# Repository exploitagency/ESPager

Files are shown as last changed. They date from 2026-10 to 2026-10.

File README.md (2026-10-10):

```
######################################
ESPager
A GSC and POCSAG Encoder for ESP32 C3
######################################
Written by Hardcore Corey Harding
######################################
Licensed: GPL v3.0
######################################
```
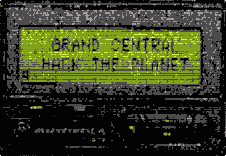
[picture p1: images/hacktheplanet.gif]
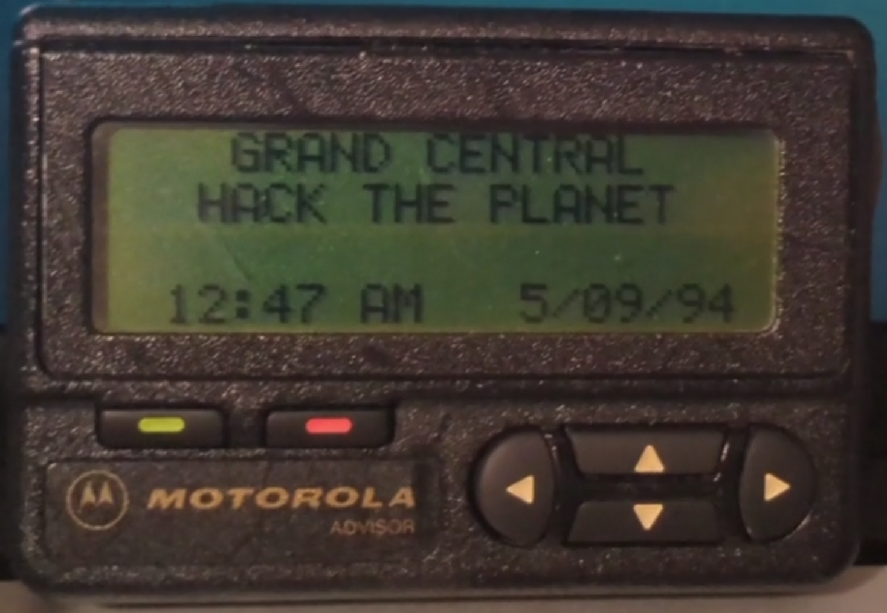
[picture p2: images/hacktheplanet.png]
   
<br>
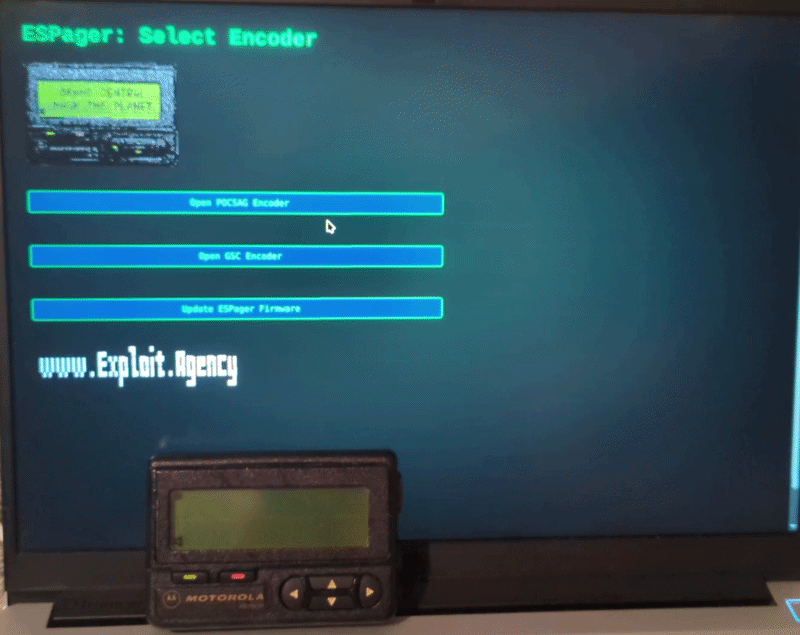
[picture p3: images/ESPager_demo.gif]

<br>

* Note: The pager related instructions are specifically tailored to the 1st Generation Motorola Advisor but ESPager should be able to send pages to similar pagers using the same methods as described in the readme.  

--------------------
# What is it?  

<i>
<table>
  <tr>
    <td><br>Video demonstrating web interface<br>(No PBX Required)</td>
    <td><br>Video demonstrating integration with PBX<br>(FreePBX 17 / Asterisk)</td>
  </tr>
</table>
</i>

* ESPager is capable of sending either GSC or POCSAG encoded pages to a pager through ESPager's retro inspired web interface.  
* The radio module is removed from the pager and replaced with an ESP32 C3.  
* The ESP32 has a GPIO pin connected directly to the pager's data in pin that was formerly occupied by the pager's radio module.  
* ESPager effectively bit bangs the encoded message directly into the pager's data in pin, thus signalling a page on the pager.  
* You can send a page either through ESPager's web interface or by using URL GET Requests with the proper parameters.  Using the GET Request API you can now more easily integrate this project into an Asterisk PBX to send a message to your pager.  

<a href="images/web_root.png">
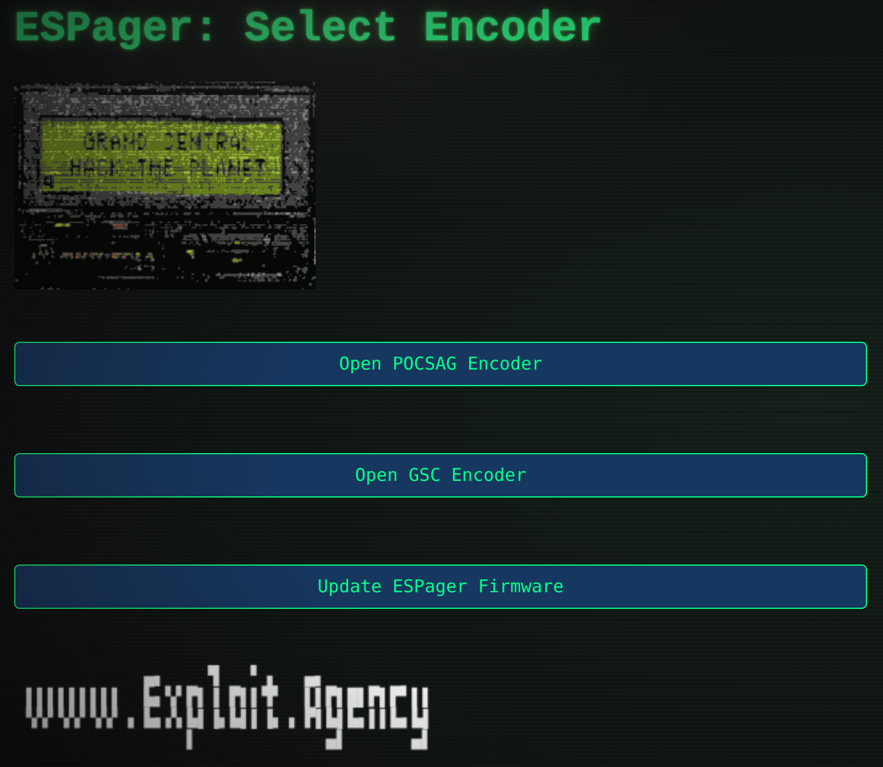
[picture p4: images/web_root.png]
Full-size image
  
</a>

<a href="images/web_pocsag_encoder.png">
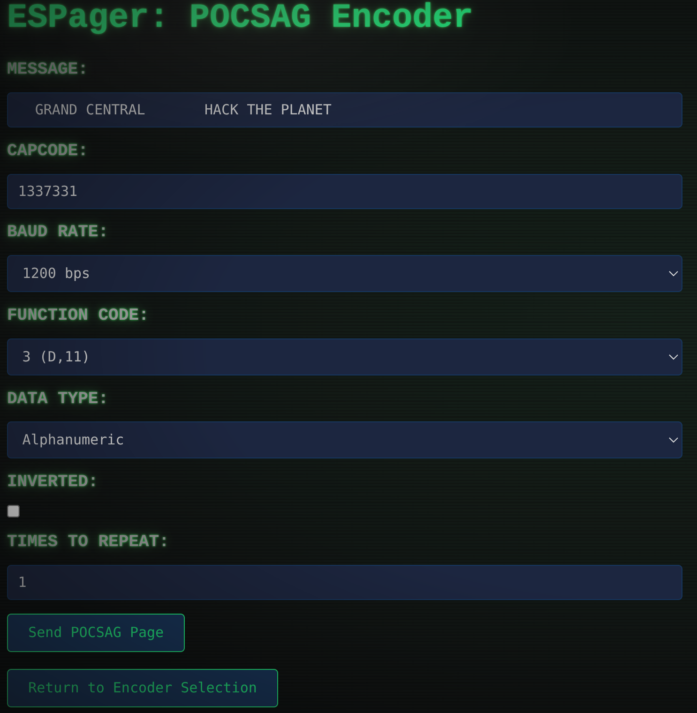
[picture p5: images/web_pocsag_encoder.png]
Full-size image
  
</a>

<a href="images/web_pocsag_encoded.png">
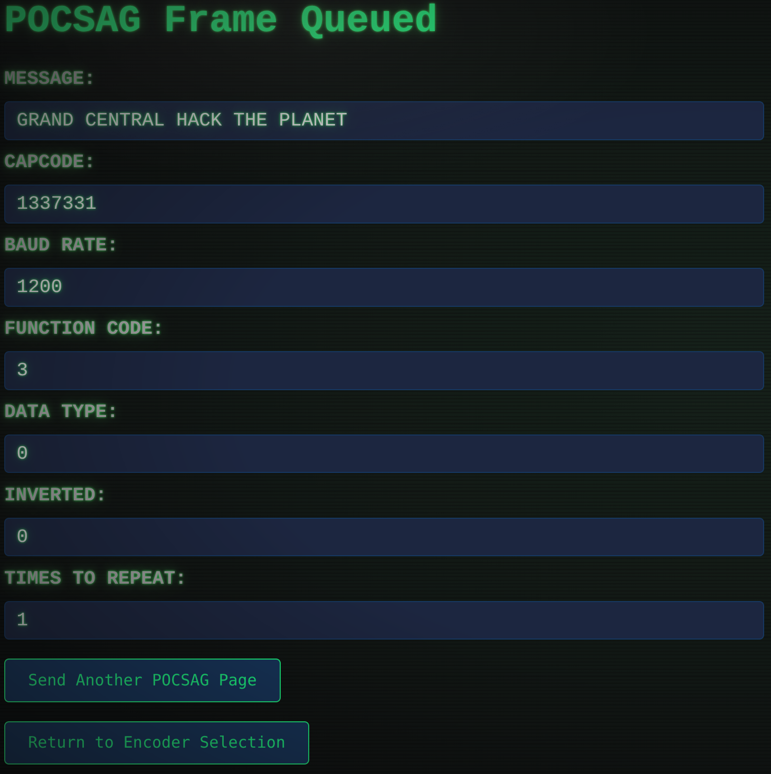
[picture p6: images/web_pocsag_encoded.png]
Full-size image
  
</a>

<a href="images/web_gsc_encoder.png">
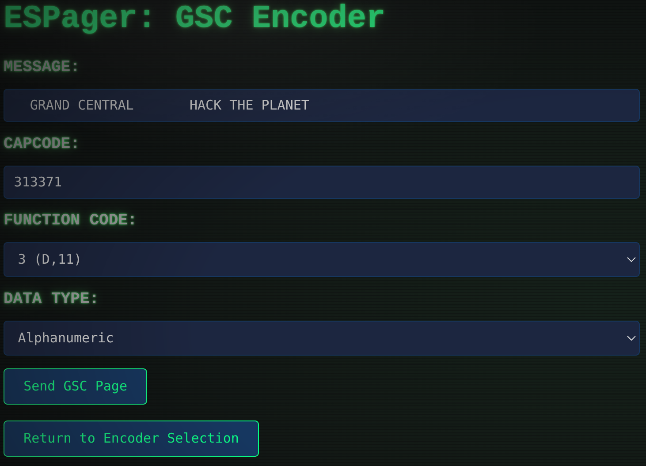
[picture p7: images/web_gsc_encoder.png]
Full-size image
  
</a>

<a href="images/web_gsc_encoded.png">
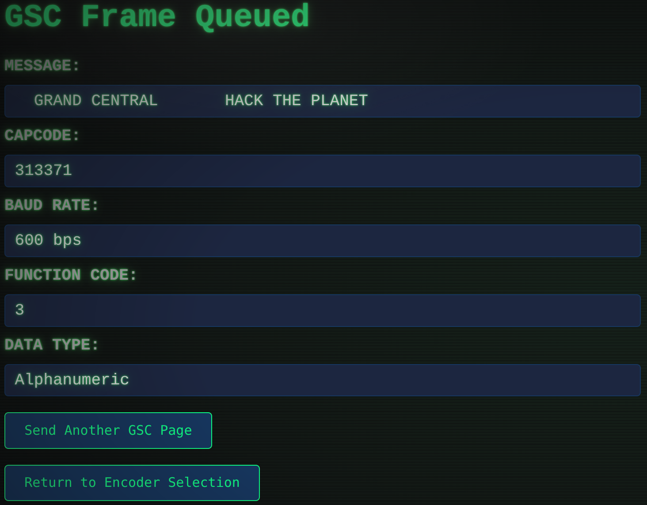
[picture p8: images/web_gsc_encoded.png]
Full-size image
  
</a>

--------------------
# BOM  

** Note: Most of these items can only be found on AliExpress or through similar vendors  
* 1st Generation Motorola Advisor (or Pager that supports POCSAG or GSC)  
* XIAO ESP32 C3 with built in battery charging (or Generic ESP32-C3 SuperMini)  
* 10440 Button-Top 3.7v Vapcell F4 450mAh (or Generic USB C Rechargeable 3.7v 10440 750mWh 200mAh, maybe a 601230?)  
* Tiny Out 1A LDO 1.8V (or mini DC-DC Buck Converter 1.5v output voltage with 2.5v-6.0v input voltage)  
* 3.7v 1S 2.5A li-ion BMS Protection Module with Overdischarge protection (Round type that goes on end of 18650 is smallest I found)  
* Assorted Color Wire (I used solid core 22awg)  
* Wiring harness tape(Tesa cloth fabric tape)  

Optional:  
* Serial UART adapter for programming pager (Worked best in DOSBOX: RadioMaster ExpressLRS USB UART Flasher V2)  
* 3d printed TPU programming POGO adapter for Motorola Advisor (Included in 3d_prints folder)  
* Male to Female DuPont jumper wires for 3d prints  

--------------------
# Instructions  

An ESP32 C3 running the code contained within this repo is installed inside a Motorola Advisor pager with slight hardware modifications.  

--------------------
### Programming the Motorola Advisor  
--------------------
* 3d print (TPU) and assemble the POGO adapter for the Motorola Advisor
* Remember to connect UARTs TX to Pagers RX and UARTs RX to Pagers TX
* Programming software is available at this repo (https://github.com/goshante/motorola-advisor-linguist) and various locations online.  
* For ESPager's default settings to work out of the box be sure to set all pager settings to exactly mirror the images below.  
<a href="images/motorola_advisor_programming_pins.jpg">
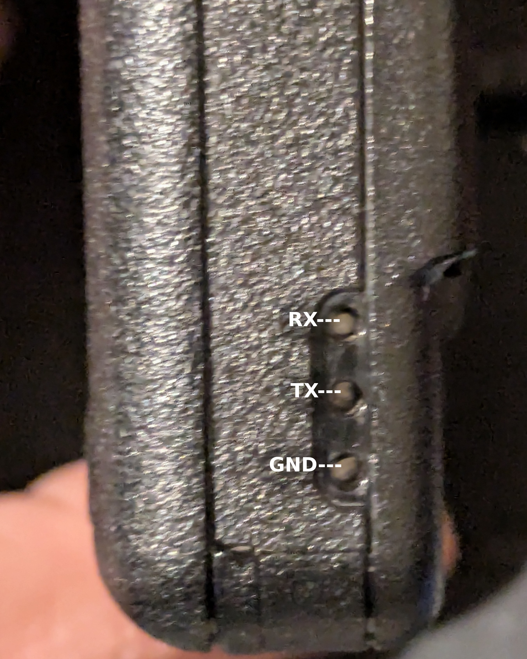
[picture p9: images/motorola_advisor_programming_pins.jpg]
Full-size image
  
</a>

<a href="images/advisor_prog_jig1.jpg">
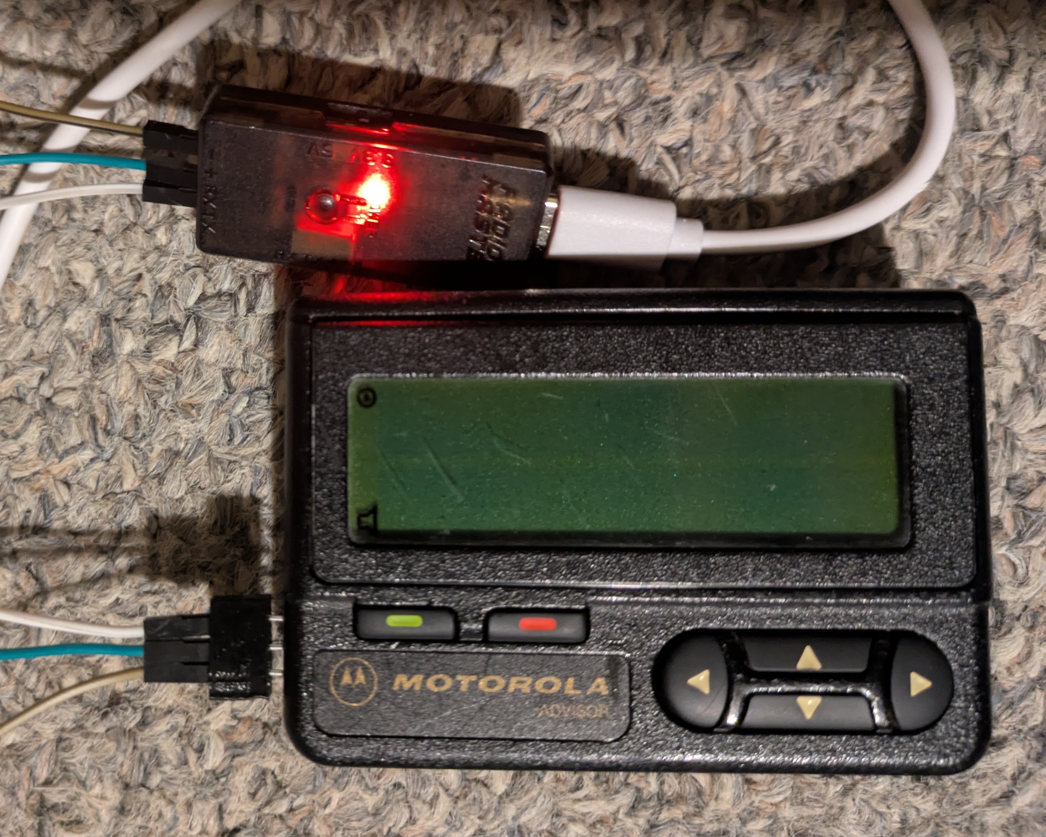
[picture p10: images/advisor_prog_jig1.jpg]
Full-size image
  
</a>

<a href="images/advisor_prog_jig2.jpg">
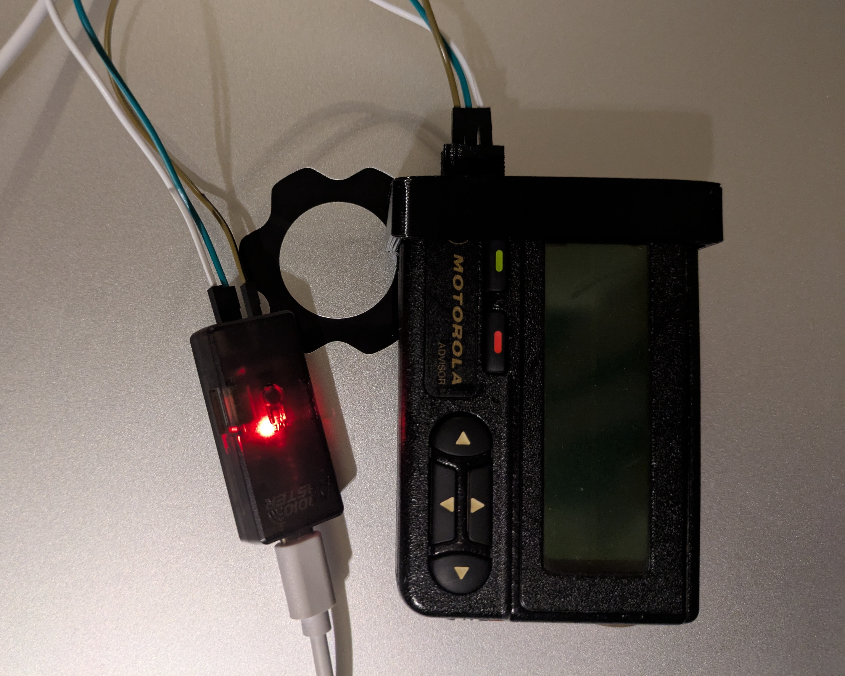
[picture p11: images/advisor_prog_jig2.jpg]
Full-size image
  
</a>

<br>

<a href="images/pocsag1.png">
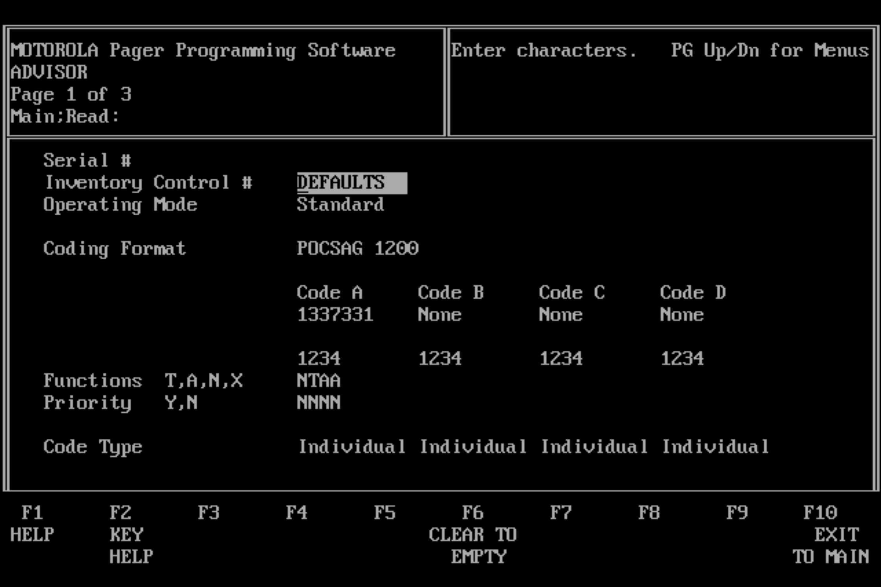
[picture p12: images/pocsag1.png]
Full-size image
  
</a>

<a href="images/pocsag2.png">
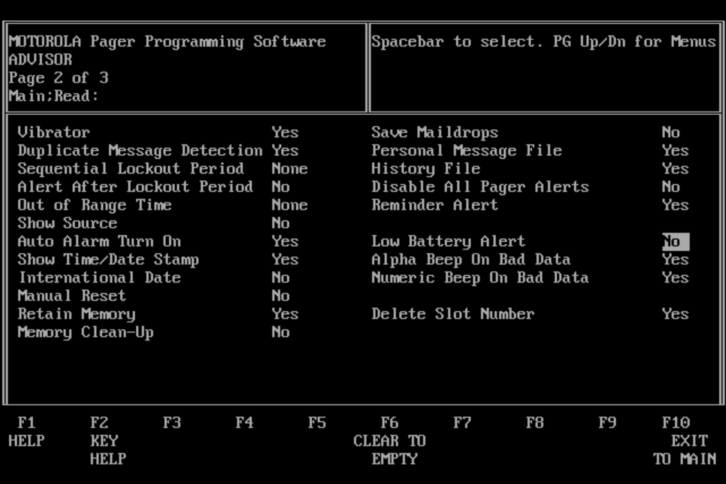
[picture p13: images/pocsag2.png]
Full-size image
  
</a>

<a href="images/pocsag3.png">
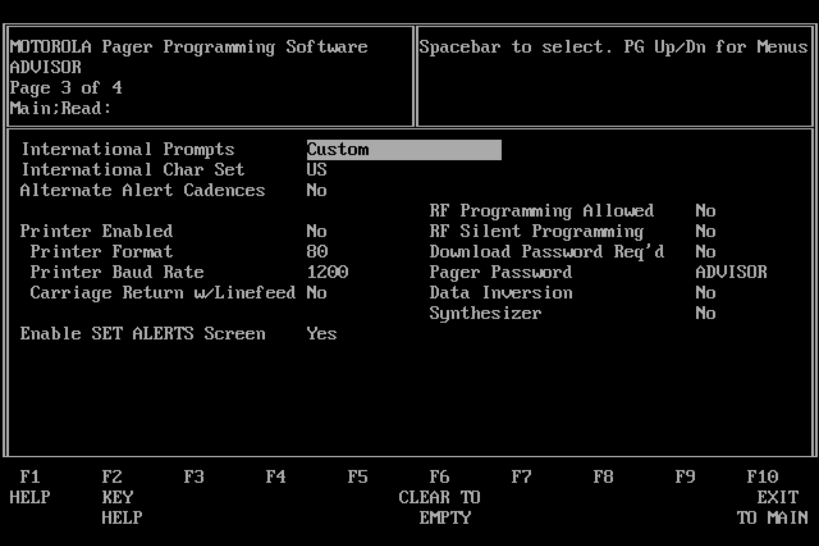
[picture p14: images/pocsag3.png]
Full-size image
  
</a>

<a href="images/pocsag4.png">
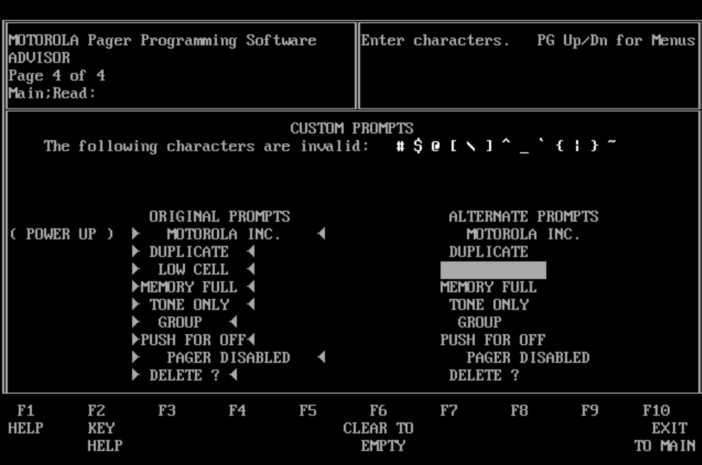
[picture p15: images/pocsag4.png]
Full-size image
  
</a>

<br>

<a href="images/gsc1.png">
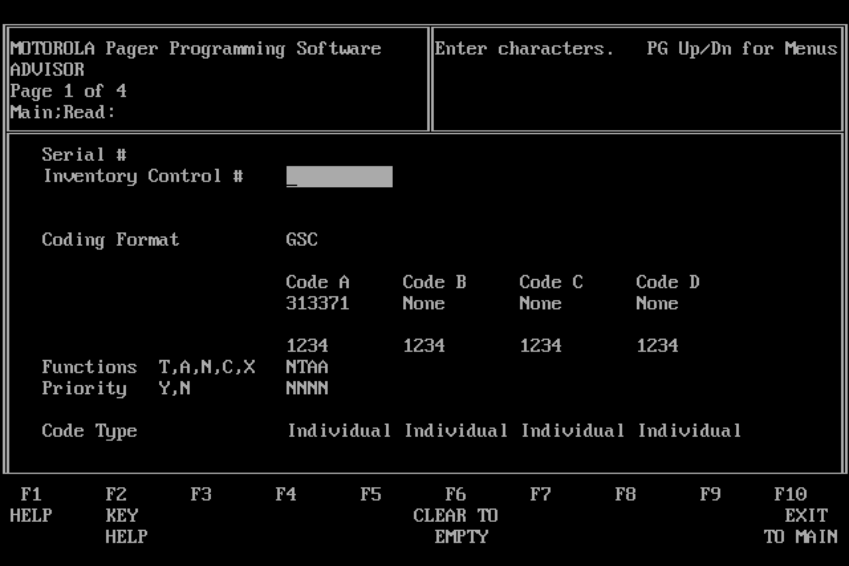
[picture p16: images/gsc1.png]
Full-size image
  
</a>

<a href="images/gsc2.png">
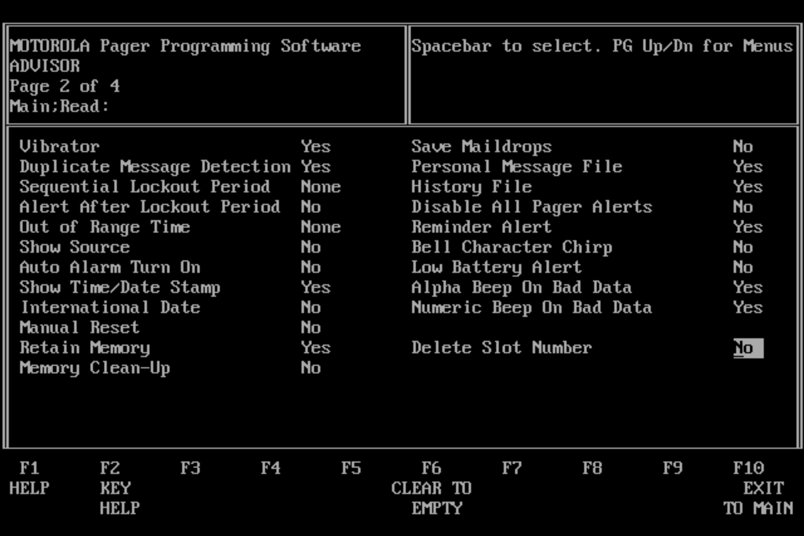
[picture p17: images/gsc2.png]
Full-size image
  
</a>

<a href="images/gsc3.png">
  Full-size image
</a>

<a href="images/gsc4.png">
  Full-size image
</a>

--------------------
### Opening the Motorola Advisor  
--------------------
* Refer to photos below instructions as you follow along.
* Slide battery tray lock away from the compartment to unlock it.  Slide battery tray cover away from the pager to open it. Remove the battery if present.
* Locate the lanyard loop pin on bottom side of the pager.  Very lightly lift the locking tab closest to the lanyard loop pin.  Slide the locking tab from the bottom and up towards the lanyard loop and it should pop out.  
* Gently pry the bottom corner near the positive battery terminal using the battery tray as leverage and the body should pop open on that side.  Gently roll the body towards the still locked side to open it.  
* Locate the radio board and gently wiggle and lift up and away from the main pcb to free it from the header pins.  
<a href="images/motorola_advisor_open_1.jpg">
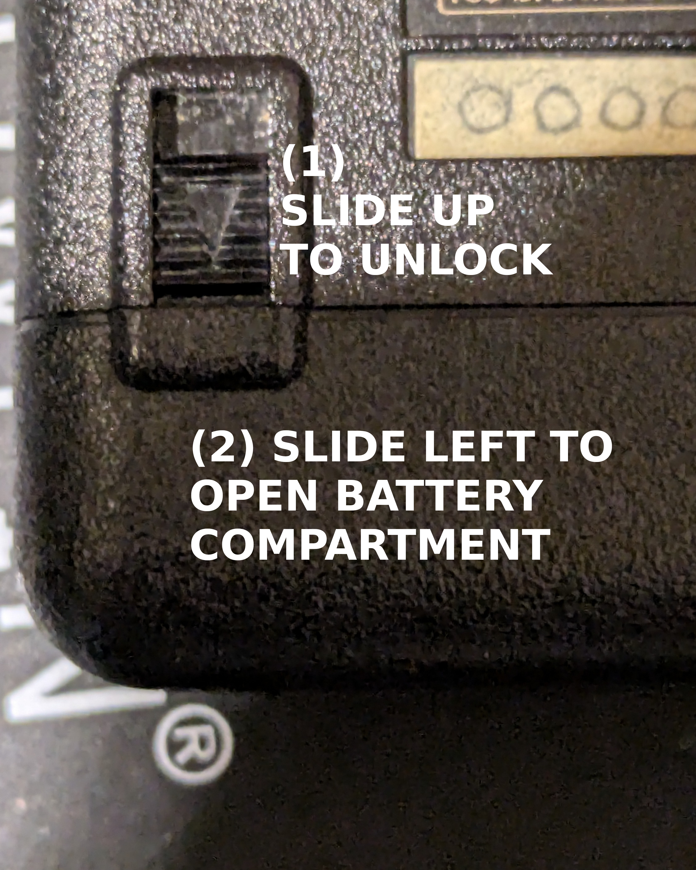
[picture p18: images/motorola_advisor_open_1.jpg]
Full-size image
  
</a>

<a href="images/motorola_advisor_open_2.jpg">
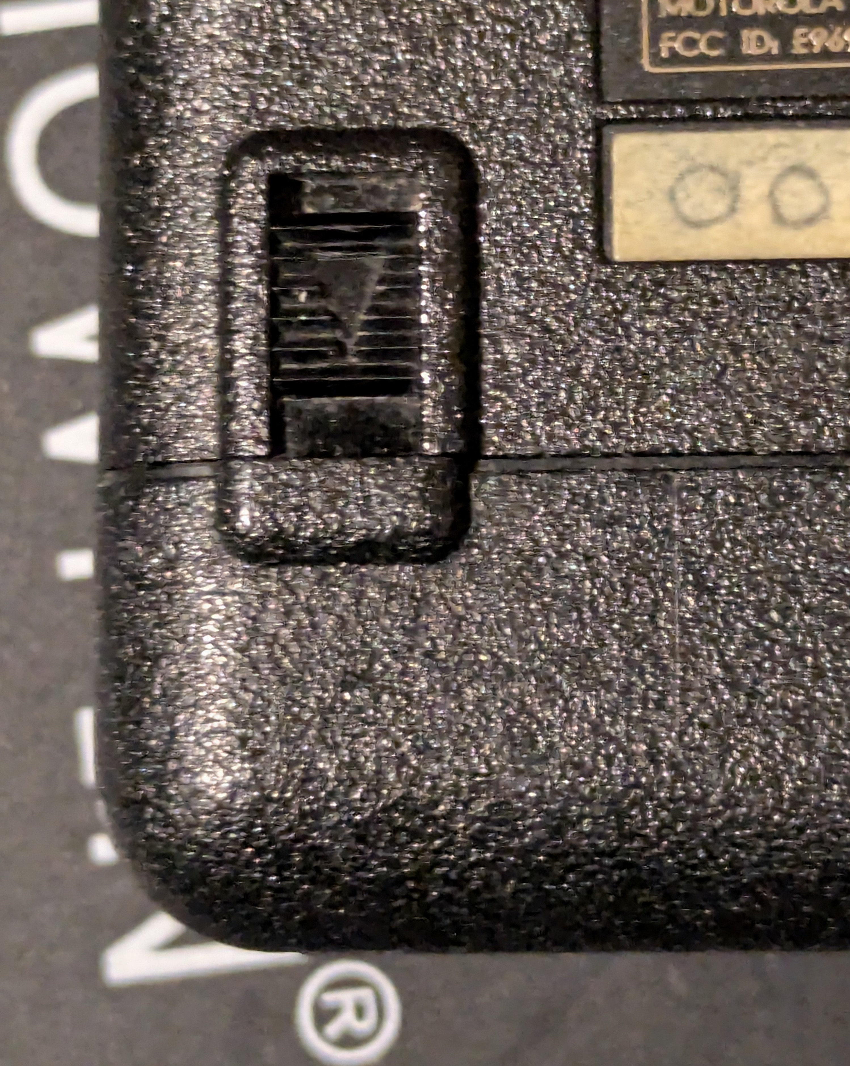
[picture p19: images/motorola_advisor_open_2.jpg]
Full-size image
  
</a>

<br>

<a href="images/motorola_advisor_open_3.jpg">
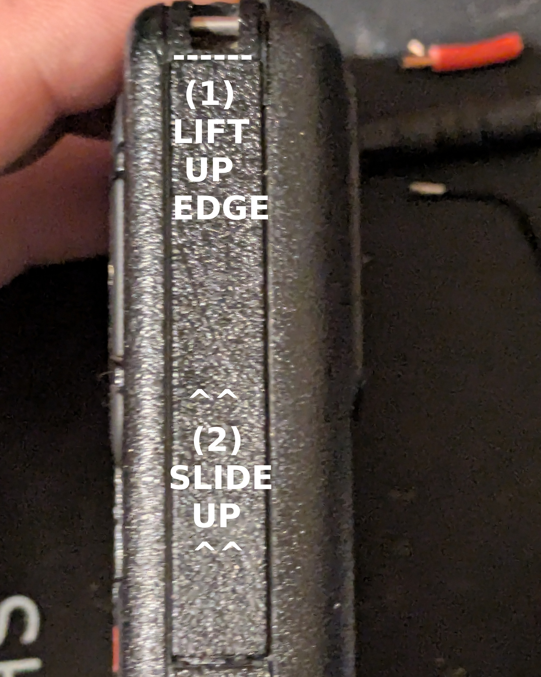
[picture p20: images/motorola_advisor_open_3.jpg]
Full-size image
  
</a>

<a href="images/motorola_advisor_open_4.jpg">
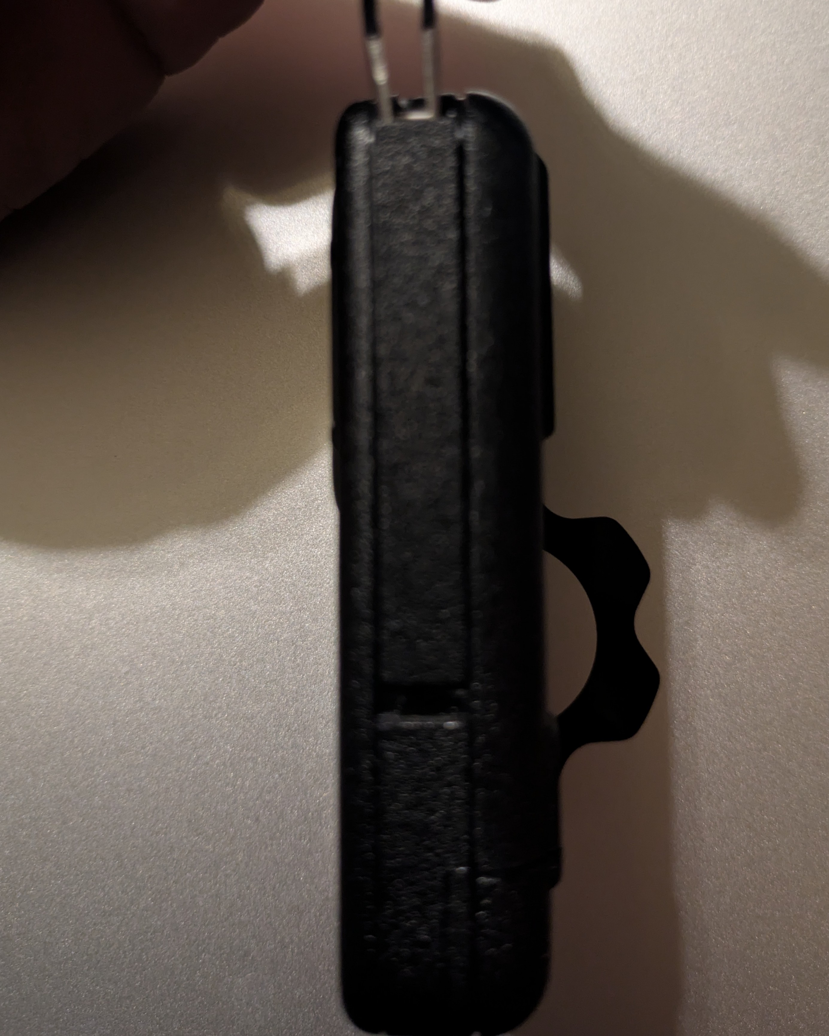
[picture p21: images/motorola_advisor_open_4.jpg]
Full-size image
  
</a>

<a href="images/motorola_advisor_open_5.jpg">
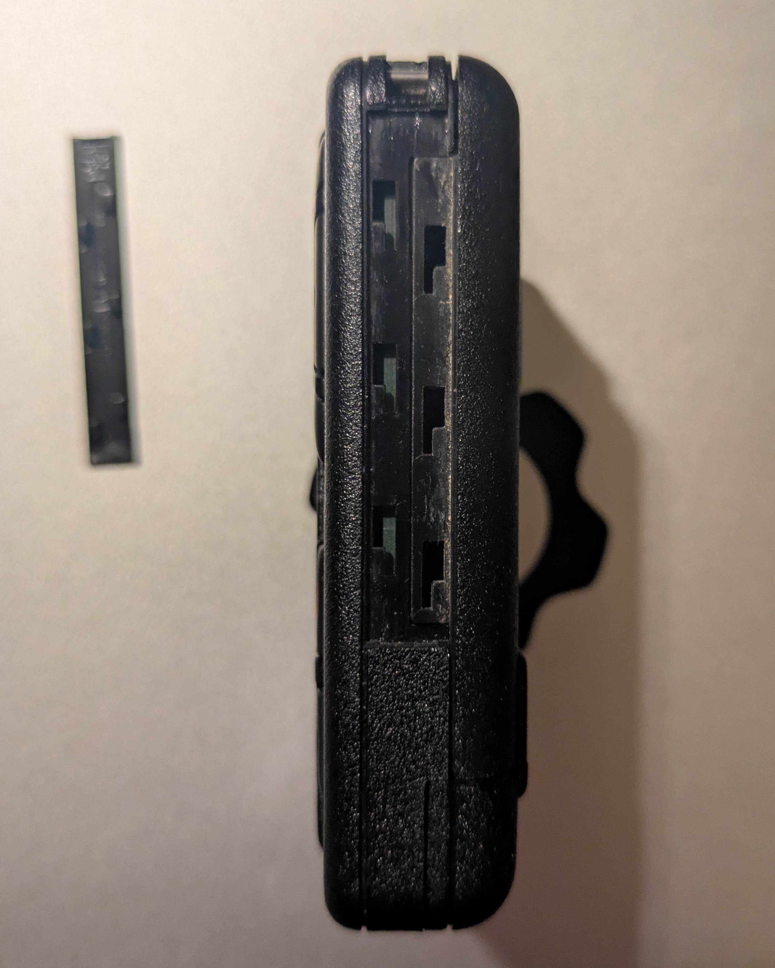
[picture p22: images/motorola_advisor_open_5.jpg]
Full-size image
  
</a>

<br>

<a href="images/motorola_advisor_open_6.jpg">
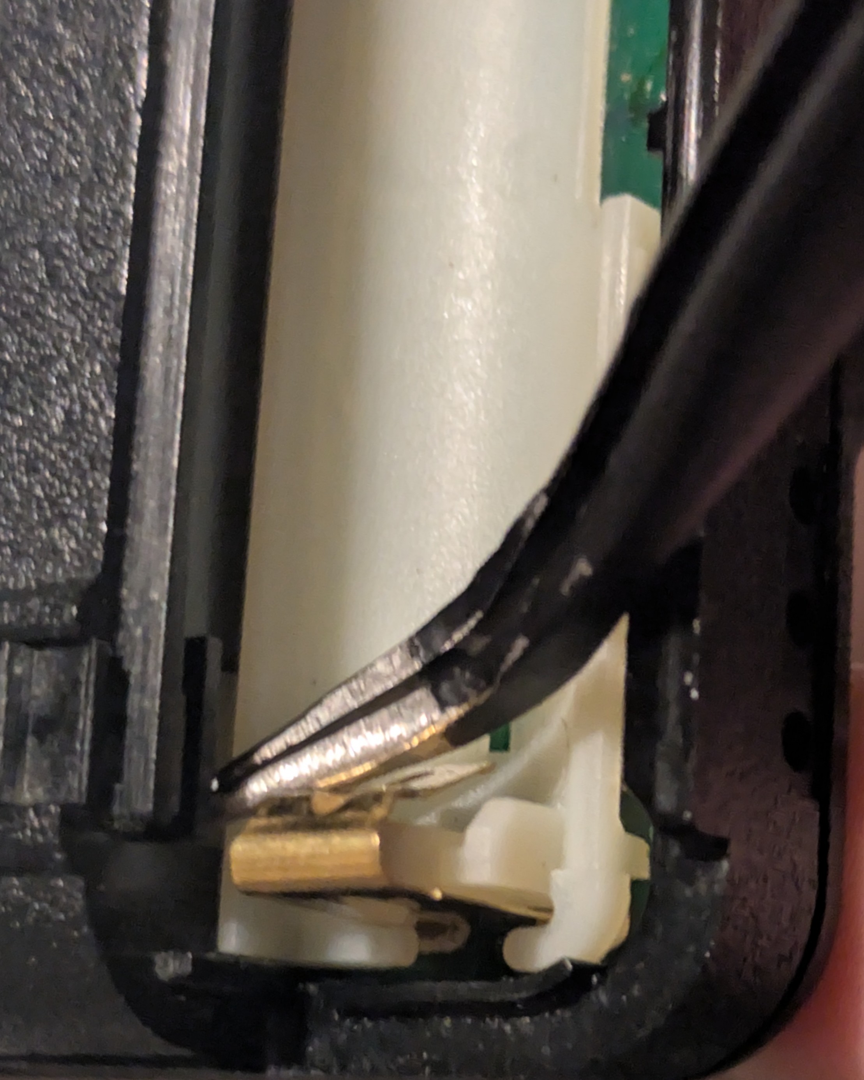
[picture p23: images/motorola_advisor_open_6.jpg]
Full-size image
  
</a>

<a href="images/motorola_advisor_open_7.jpg">
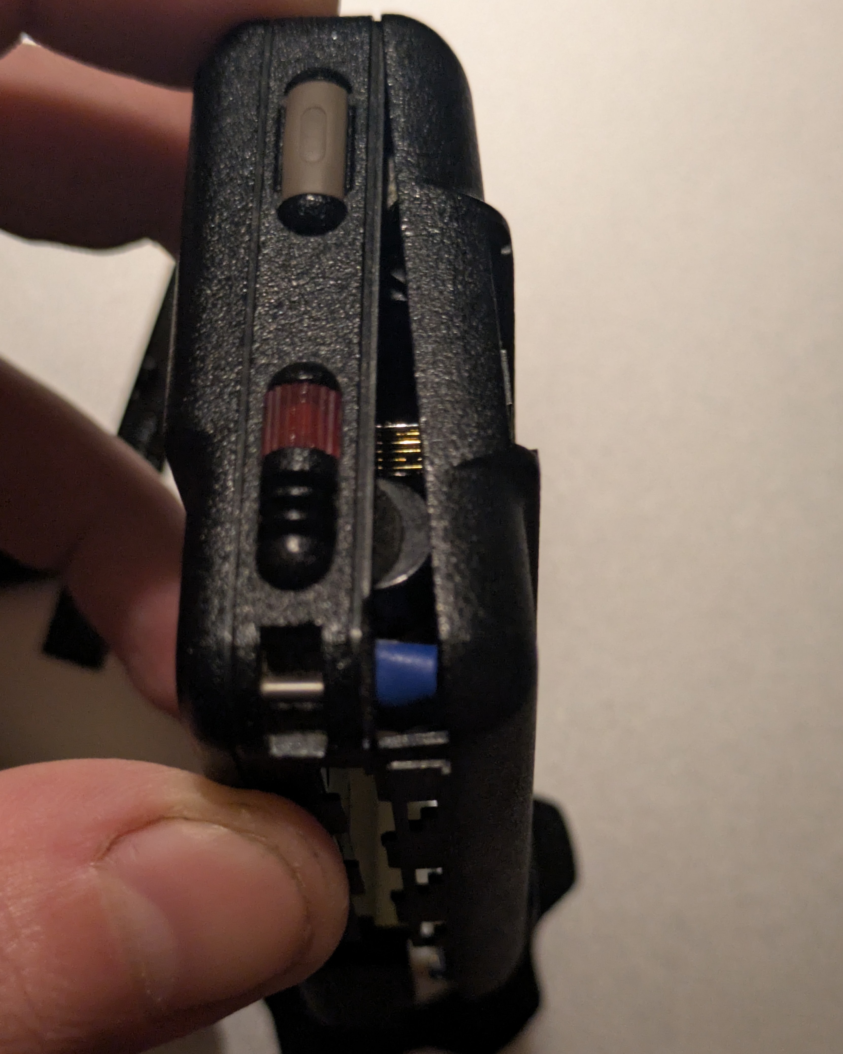
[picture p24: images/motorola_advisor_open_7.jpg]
Full-size image
  
</a>

<a href="images/motorola_advisor_open_8.jpg">
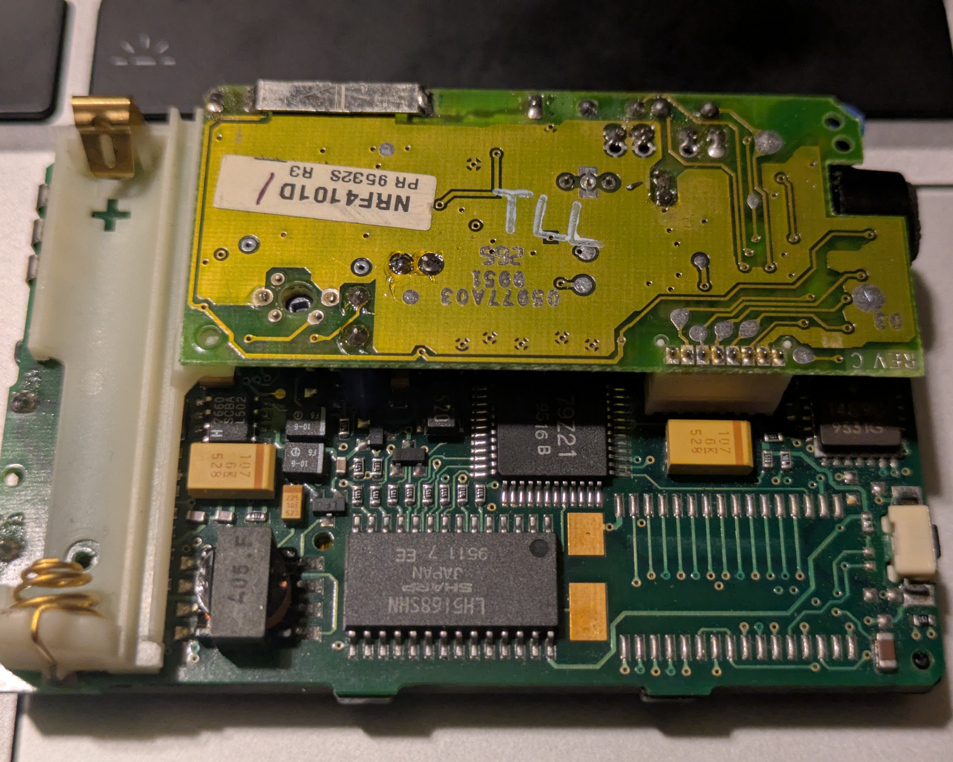
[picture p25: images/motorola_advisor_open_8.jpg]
Full-size image
  
</a>

--------------------
### Modifying the Motorola Advisor and Installing ESP32 C3  
--------------------

** WARNING: Do not connect USB when battery power is also connected unless your board has specific hardware to support it!  
* Desolder the battery holder.  On the positive side clip the legs off the bottom that protrude through the pcb.  On the negative side, bend the leg towards the inside of the pager.  Solder you main battery wires to the battery holder.  Clip the corner of the pager's rear cover as pictured to make room for the battery wire to pass through.  Clip the nub off the bottom of the battery holder under the positive side to make room for the wiring underneat it.  
* Solder the 3.7v wires from the battery holder to the BMS input as seen in wiring diagram.  
* Solder the 3.7v wires from the BMS output directly to the ESP32-C3's 5v input and GND and to the 1.5v buck converters input as seen in wiring diagram.(ESP32-C3 5v input can be powered by 3.5v-6v and a fully charged 10440 is 4.2v)  
* Solder the 1.5v wires onto the pager's main pcb as pictured and solder those wires to the output of the buck converter as seen in wiring diagram.  Cover the wires on the pager's main pcb to prevent feeding the pager 3.7v if the battery trays positive somehow made contact.  
* Solder GPIO 3(Sleep) on the ESP32 C3 to header pin 7(pulse when pager is on) on the pager, solder GPIO 7(Data out) on ESP32-C3 to header pin 4(Data In) of pager.  
* Verify that the ESP32 and pager share a common ground plane by checking continuity between both grounds.  If not connect the ground from ESP32 to a ground on the pager, but I have a common ground plane through my power supply configuration.  
* Tape off the inside of the pager to prevent shorts, tape of the bms, buck converter, and ESP32-C3.  
* Assembly is reverse of disassembly.  

<a href="images/ESPager_wiring_XIAO_tinyout1a.png">
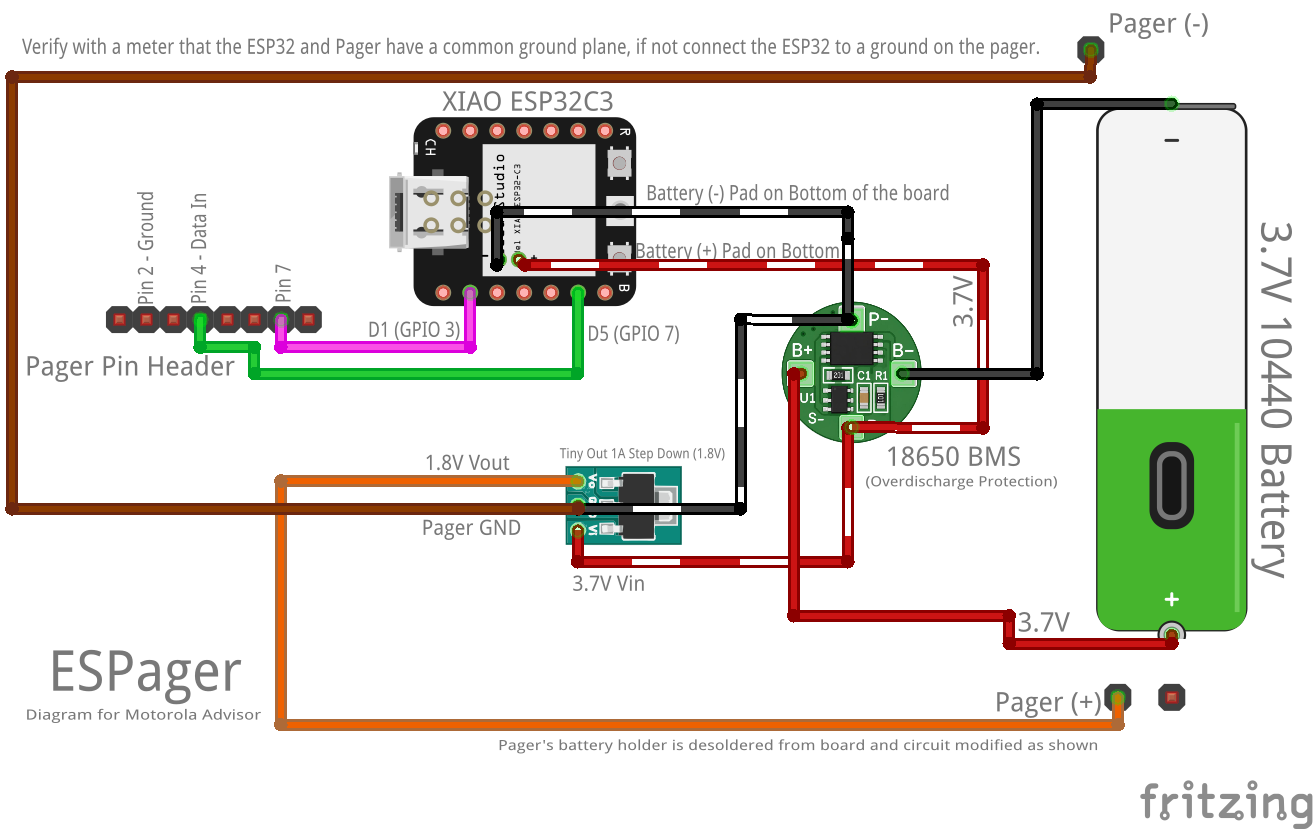
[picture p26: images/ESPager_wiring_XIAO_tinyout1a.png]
Full-size image
  
</a>

<a href="images/ESPager_wiring_XIAO.png">
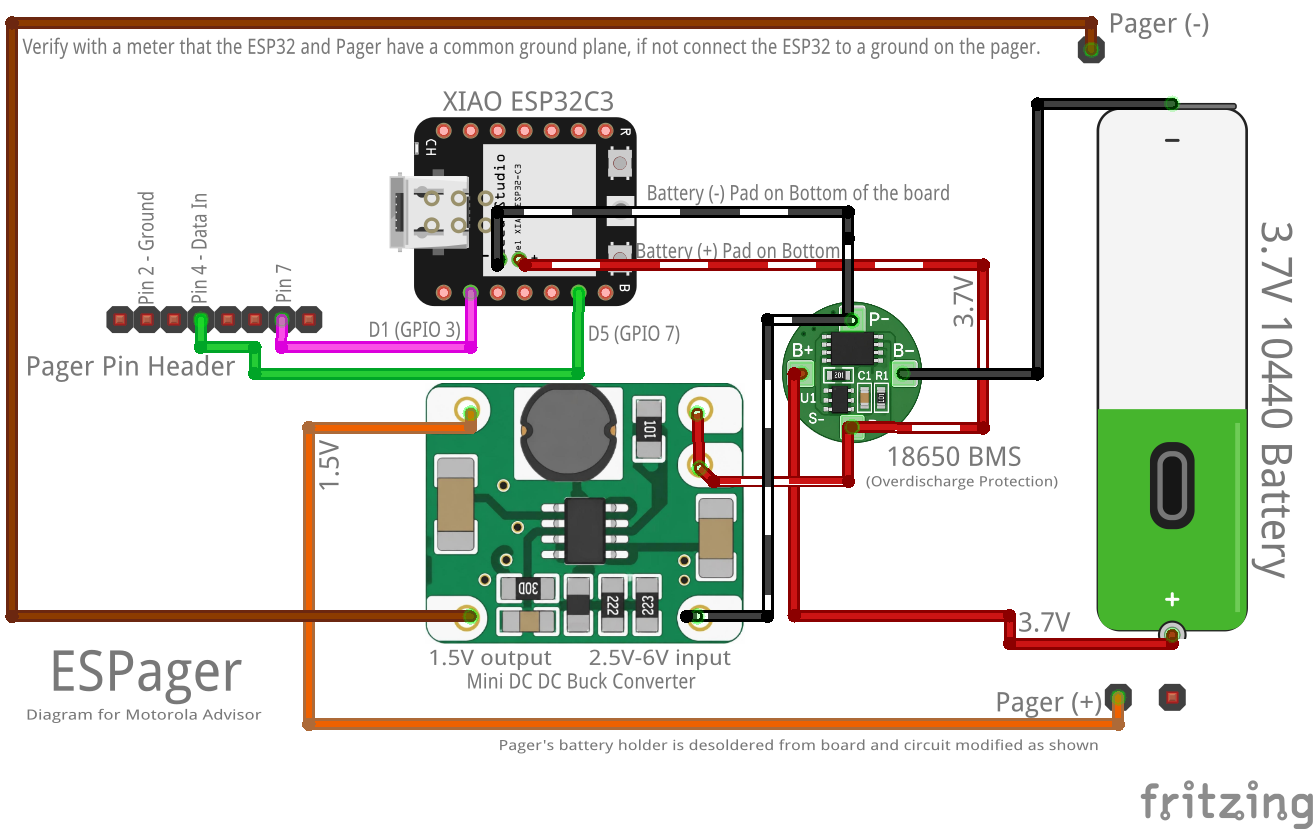
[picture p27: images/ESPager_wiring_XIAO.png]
Full-size image
  
</a>

<a href="images/ESPager_wiring.png">
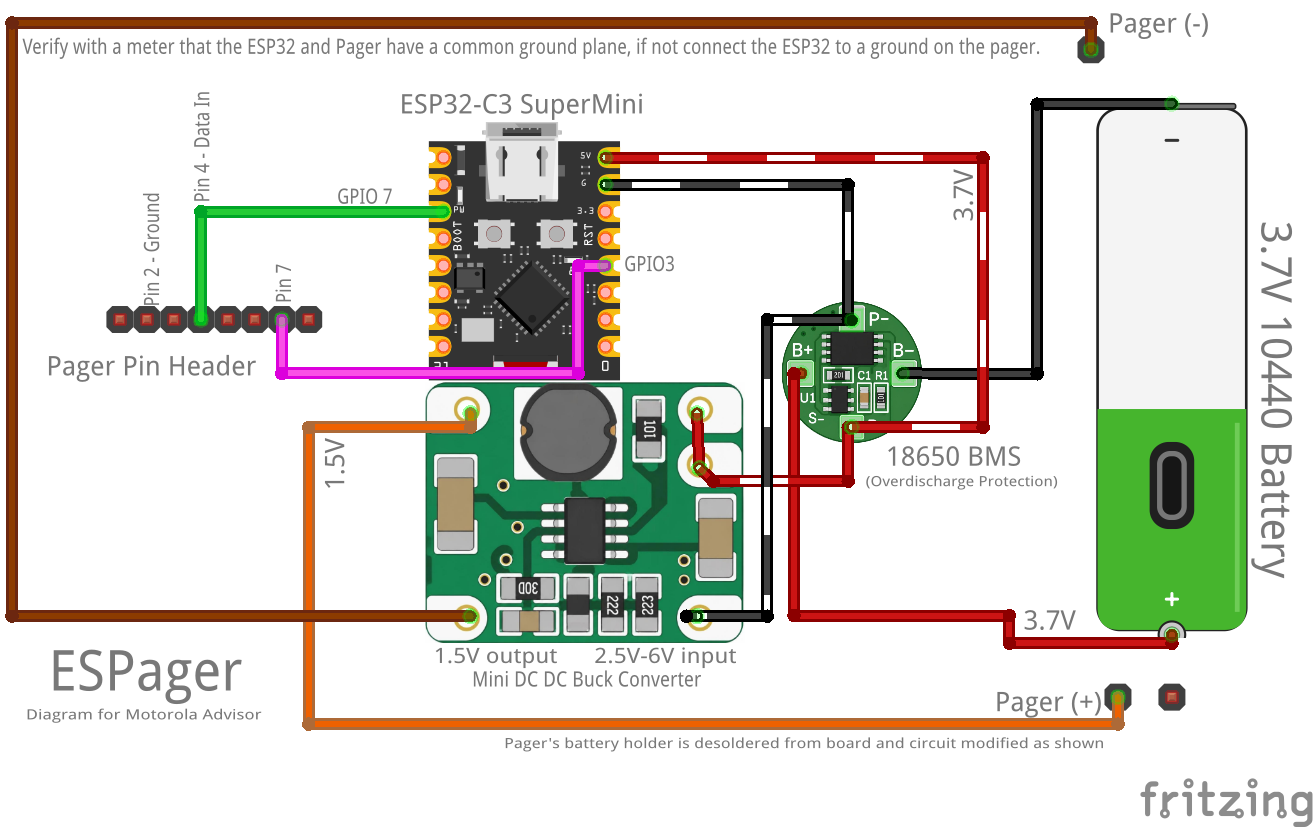
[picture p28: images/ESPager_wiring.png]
Full-size image
  
</a>

<br>

<a href="images/motorola_advisor_radio_header.jpg">
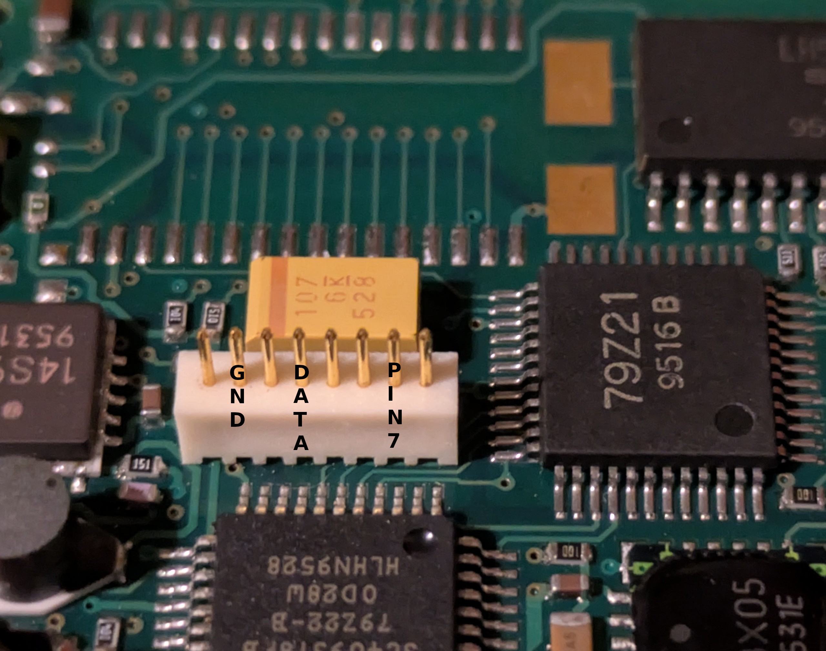
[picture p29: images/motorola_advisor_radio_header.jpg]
Full-size image
  
</a>

<br>

<a href="images/motorola_advisor_battery_tray_negative.jpg">
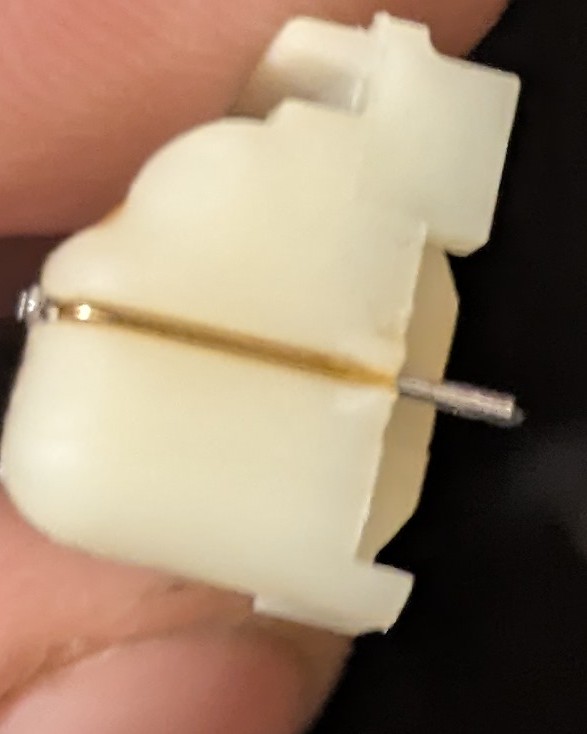
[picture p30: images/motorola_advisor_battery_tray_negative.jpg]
Full-size image
  
</a>

<a href="images/motorola_advisor_battery_tray_positive.jpg">
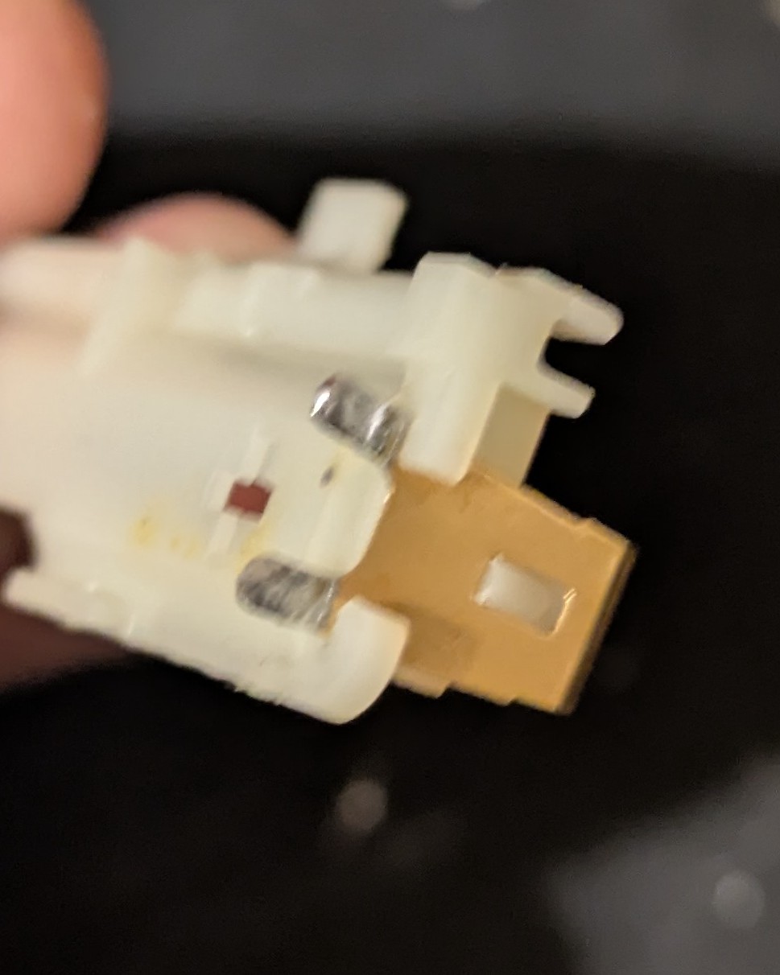
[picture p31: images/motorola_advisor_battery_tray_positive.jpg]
Full-size image
  
</a>

<a href="images/motorola_advisor_battery_tray_negative_mod.jpg">
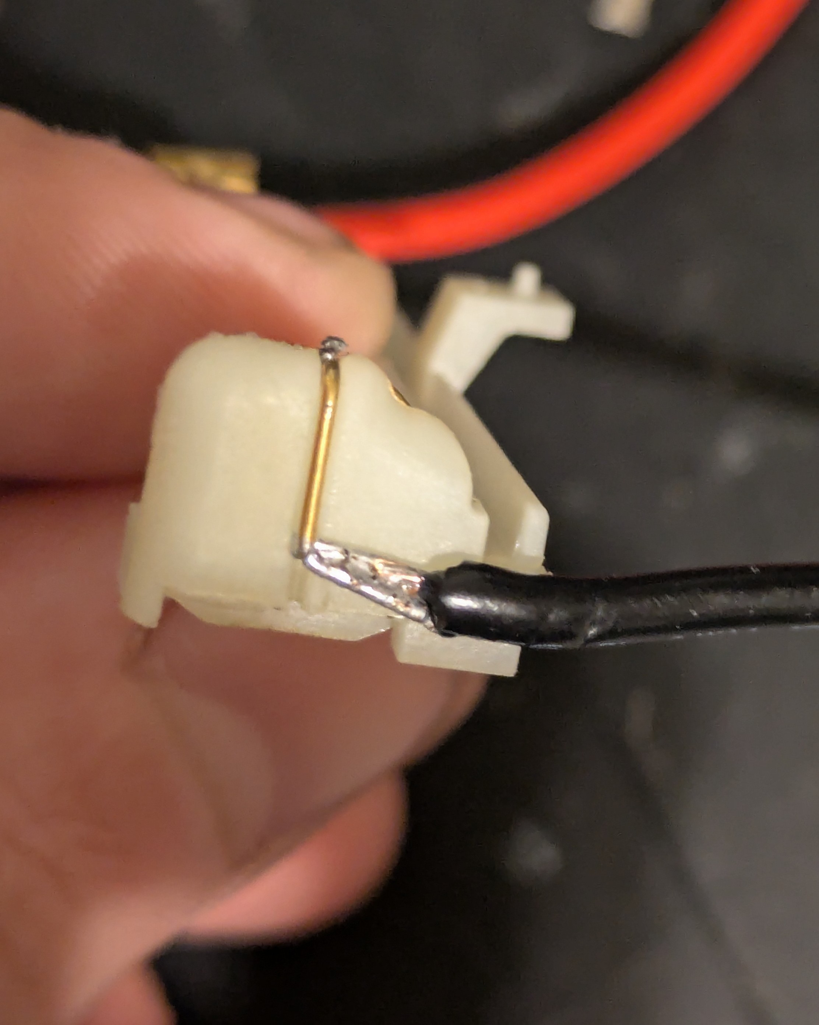
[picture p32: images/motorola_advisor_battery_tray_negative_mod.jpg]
Full-size image
  
</a>

<a href="images/motorola_advisor_battery_tray_positive_mod.jpg">
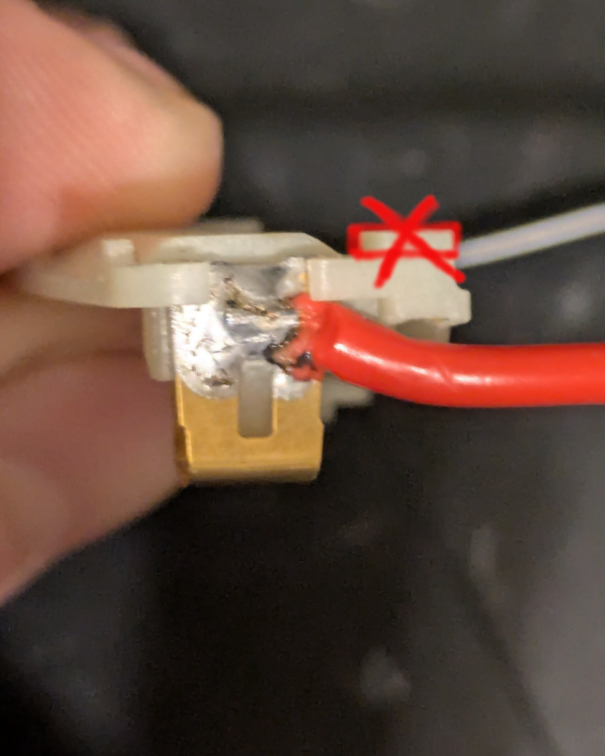
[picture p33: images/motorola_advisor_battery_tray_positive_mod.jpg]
Full-size image
  
</a>

<br>

<a href="images/motorola_advisor_battery_tray_removed.jpg">
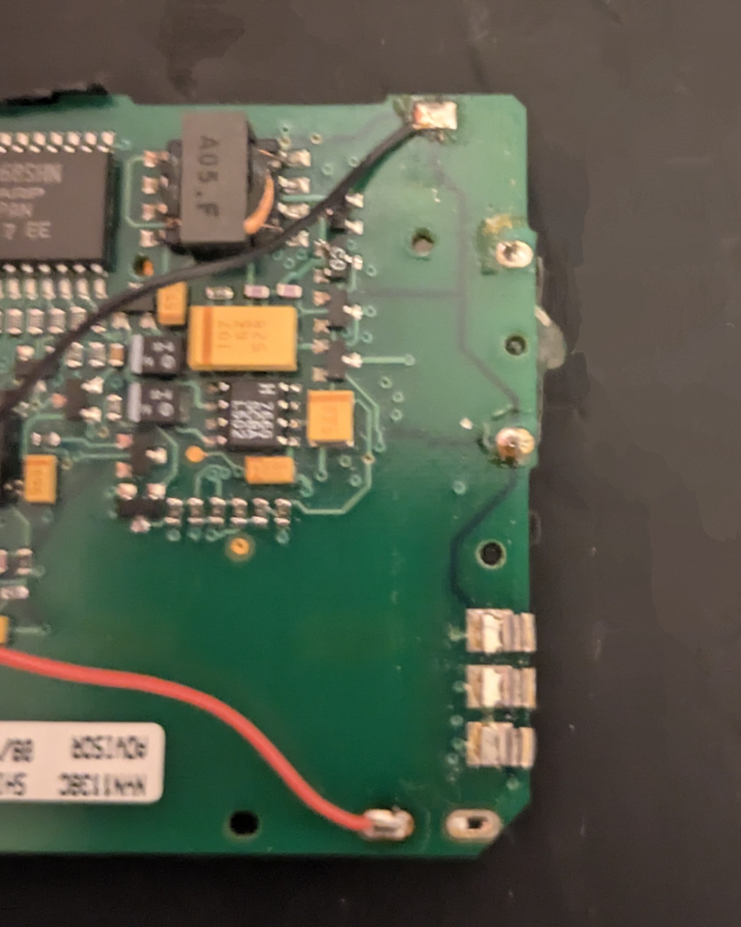
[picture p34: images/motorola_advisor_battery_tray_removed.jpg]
Full-size image
  
</a>

<a href="images/motorola_advisor_battery_tray_trim.jpg">
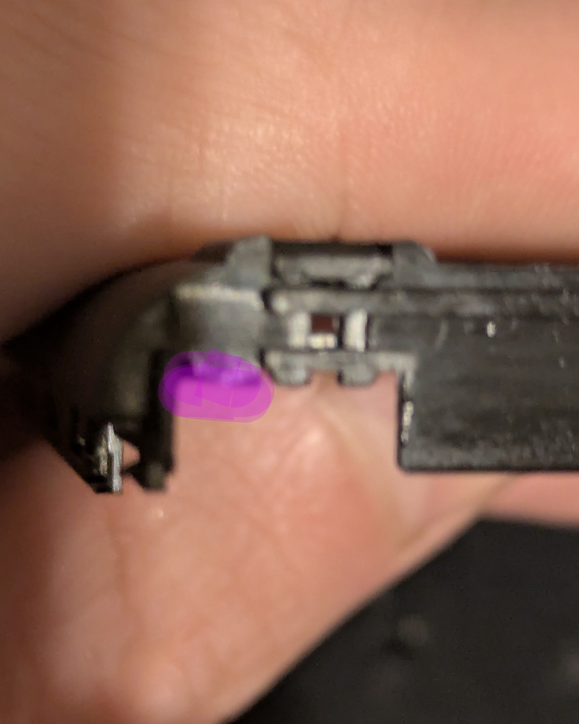
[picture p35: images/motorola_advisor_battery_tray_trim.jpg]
Full-size image
  
</a>

<a href="images/motorola_advisor_battery_tray_closeup.jpg">
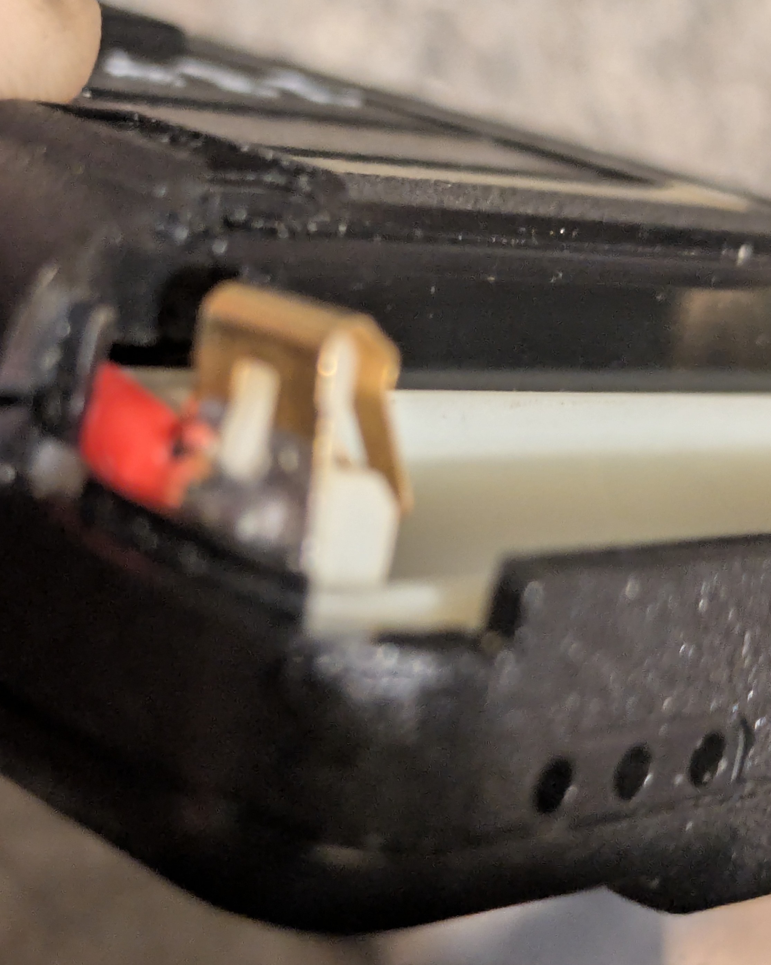
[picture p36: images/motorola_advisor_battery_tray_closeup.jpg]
Full-size image
  
</a>

<a href="images/motorola_advisor_battery_tray_complete.jpg">
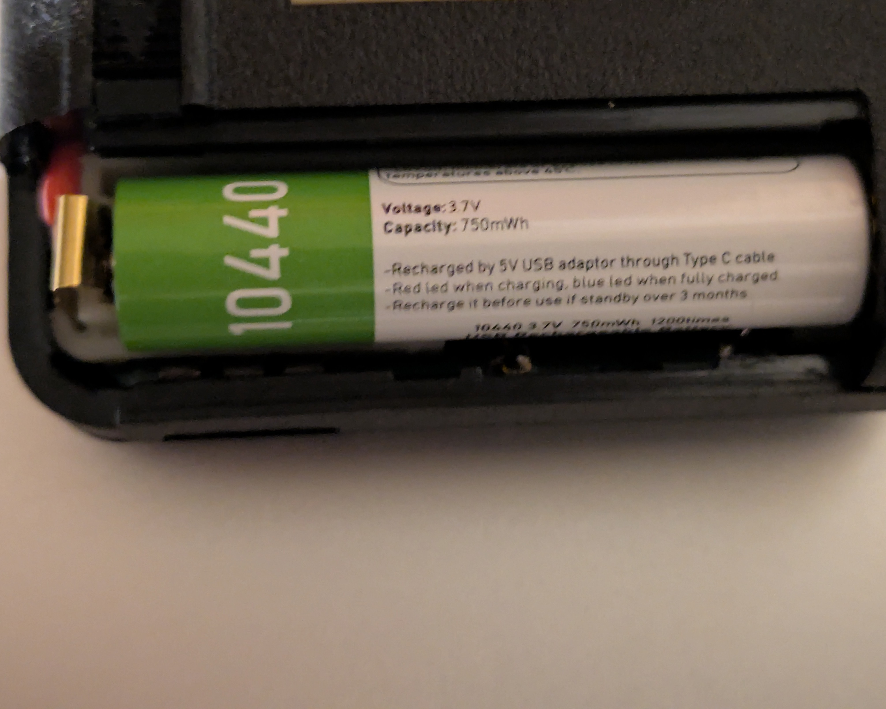
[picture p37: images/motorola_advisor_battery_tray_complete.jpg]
Full-size image
  
</a>

<br>

<a href="images/ESPAGER_XIAO_1.jpg">
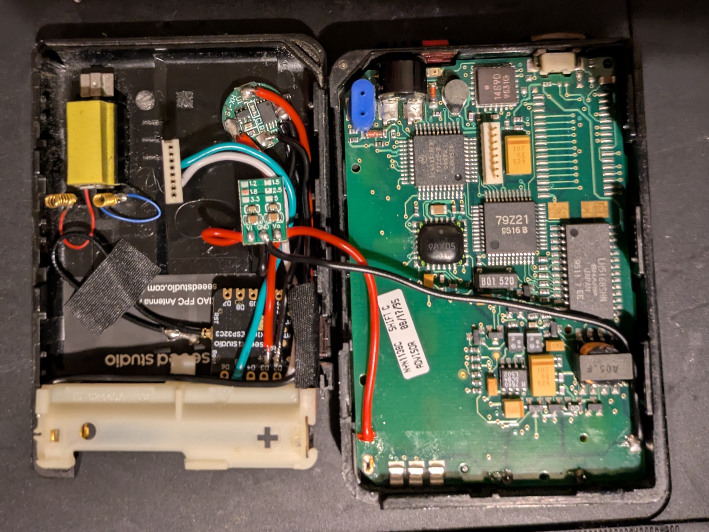
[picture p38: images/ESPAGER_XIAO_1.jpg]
Full-size image
  
</a>

<a href="images/ESPAGER_XIAO_2.jpg">
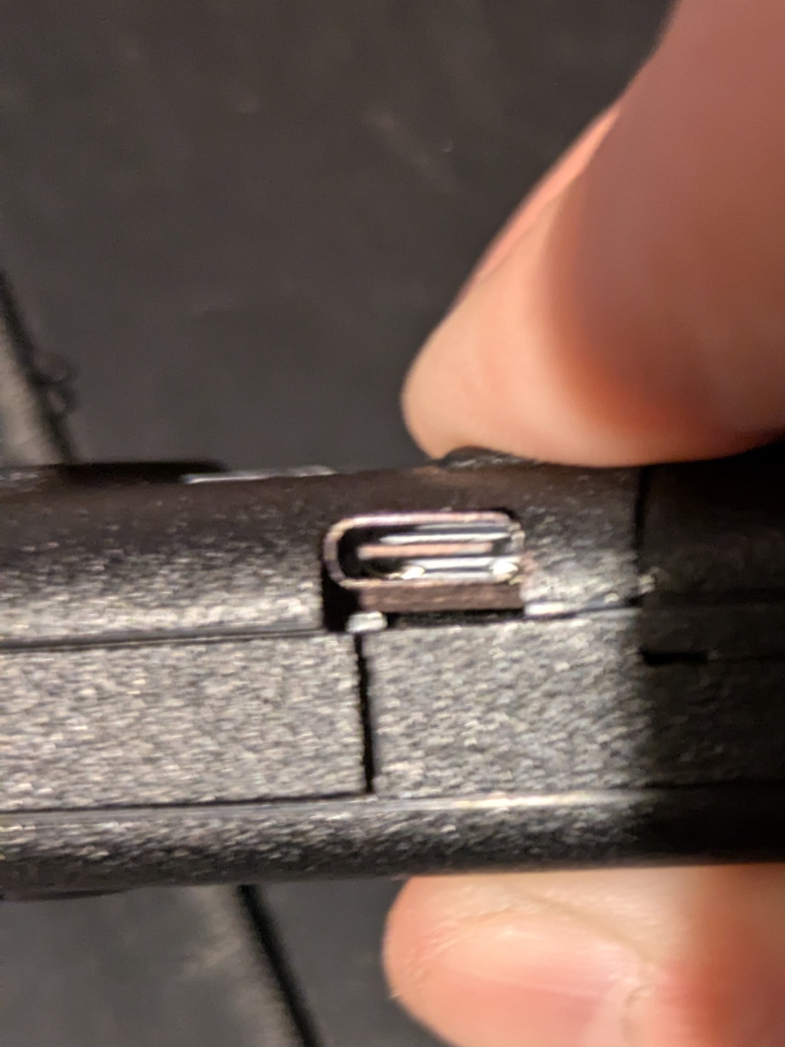
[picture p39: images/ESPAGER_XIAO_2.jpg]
Full-size image
  
</a>

--------------------
### Accessing ESPocsag 
--------------------

* If using a prebuilt binary ESPager starts in AP mode.  But if you wish to configure your own settings then modify the settings.h file and compile and flash your own build.  

* Via WiFi  
** STA MODE: http://ESPager  
** AP MODE: http://192.168.4.1  

* POCSAG API EXAMPLE  
** STA MODE: http://ESPager/pocsag?msg=TEST+MESSAGE&cap=1337331&baud=1200&function_code=3&data_type=0&repeat=1  
** AP MODE:  http://192.168.4.1/pocsag?msg=TEST+MESSAGE&cap=1337331&baud=1200&function_code=3&data_type=0&repeat=1  

* GSC API EXAMPLE  
** STA MODE: http://ESPager/gsc?msg=TEST+MESSAGE&cap=313371&function_code=3&data_type=1  
** AP MODE:  http://192.168.4.1/gsc?msg=TEST+MESSAGE&cap=313371&function_code=3&data_type=1  

--------------------
### PBX Integration
--------------------

* Refer to the readme located at [./Asterisk_FreePBX_17/README.md](Asterisk_FreePBX_17/README.md)

--------------------
# Bonus Information (Unrelated to this repo)  

--------------------
##### Bonus: Motorola Advisor Test Mode for Radio (Unrelated to this repo)  
--------------------
* Press power button
* Press red button to confirm power down
* Press green button
* Press up arrow
* Press left arrow
* Press red button
* Observe the red light on the radio is lit up to confirm radio is in test mode

--------------------
##### Bonus: Motorola Advisor CMOS Chip (Unrelated to this repo)  
--------------------
* Pinout for CMOS Chip U2 (https://github.com/goshante/motorola-advisor-linguist/blob/master/schematics/main/chematics.png)
* CMOS memory address 0x25
* Set bit 0 to 1 to enable a disabled pager
* Set bit 5 to 0 to disable the programming password requirement

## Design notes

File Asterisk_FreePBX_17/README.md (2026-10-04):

----------
STEP 1: Add Custom Dialplan  
----------
<a href="config_edit.png">
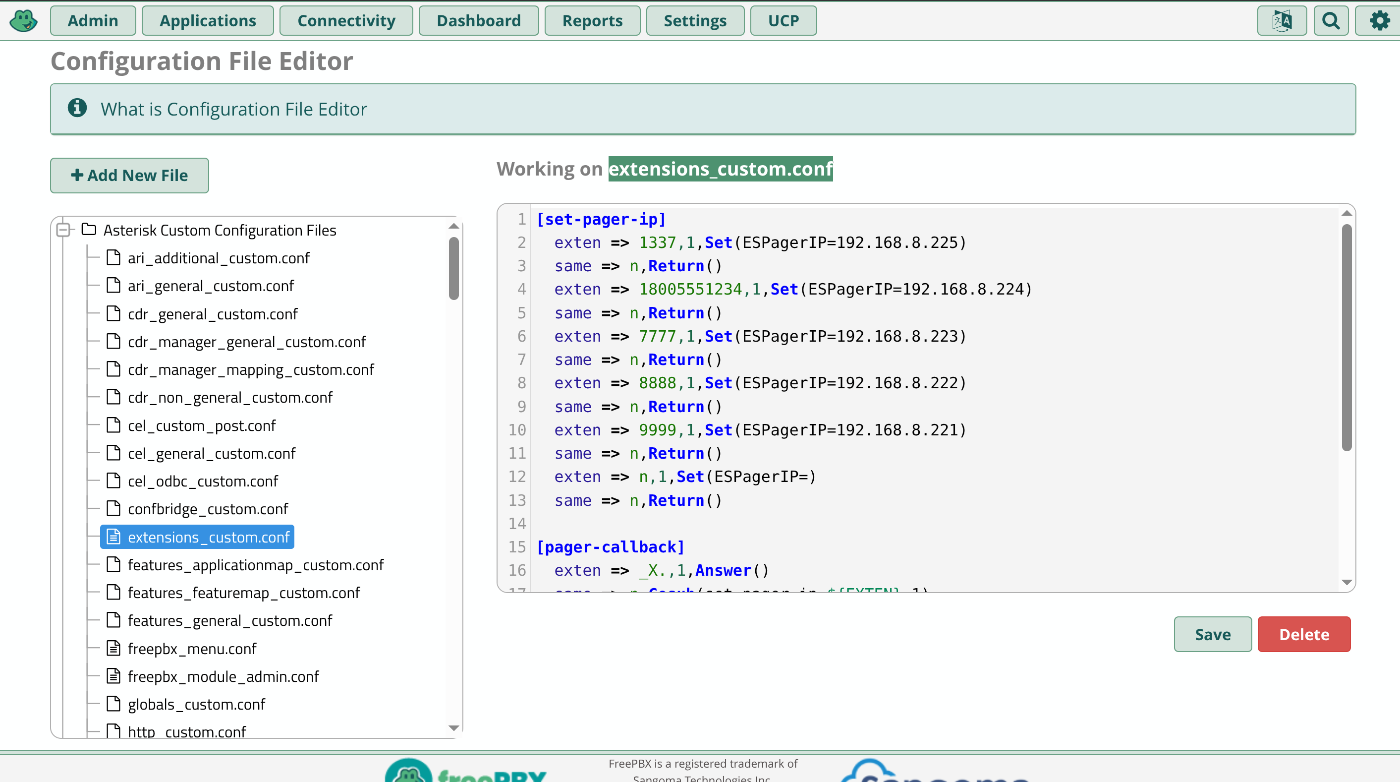
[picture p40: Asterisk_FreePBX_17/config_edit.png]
  
</a>
<br>
Admin->Config Edit->extensions_custom.conf  

```
[set-pager-ip]
  exten => 1337,1,Set(ESPagerIP=192.168.8.225)
  same => n,Return()
  exten => 18005551234,1,Set(ESPagerIP=192.168.8.224)
  same => n,Return()
  exten => 7777,1,Set(ESPagerIP=192.168.8.223)
  same => n,Return()
  exten => 8888,1,Set(ESPagerIP=192.168.8.222)
  same => n,Return()
  exten => 9999,1,Set(ESPagerIP=192.168.8.221)
  same => n,Return()
  exten => n,1,Set(ESPagerIP=)
  same => n,Return()

[pager-callback]
  exten => _X.,1,Answer()
  same => n,Gosub(set-pager-ip,${EXTEN},1)
  same => n,Flite(Please enter your call back number followed by the pound key)
  same => n,Set(TIMEOUT(digit)=5)
  same => n,Set(TIMEOUT(response)=10)
  same => n,Read(CALLBACKNUM,,#)
  same => n,Verbose(1,Callback number received: ${CALLBACKNUM})
  same => n,Set(CURL_RESULT=${CURL(http://${ESPagerIP}/pocsag?msg=${CALLBACKNUM})})
  same => n,Flite(Your call back number has been sent to the pager Goodbye)
  same => n,Hangup()
```

Save and Apply Config  

Note: I have manually installed and loaded the Flite app via command line as my TTS engine, you may find it easier to use prerecorded wav files as your voice prompts.  

If you do not wish to use Flite then replace instances of:  
```
same => n,Flite(Spoken Text)
```
With:  
```
same => n,Playback(my-recording)
```

----------
STEP 2: Add Custom Destination  
----------
<a href="custom_destinations.png">
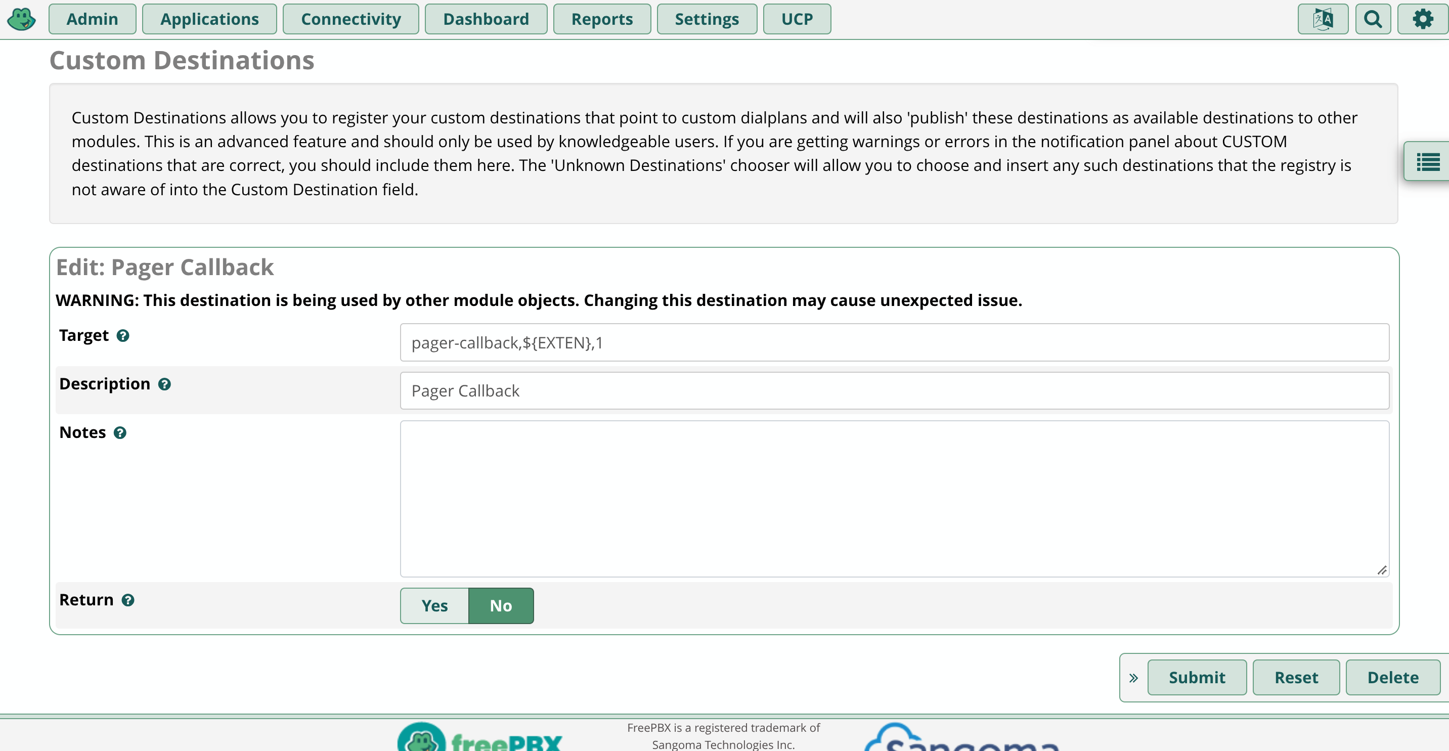
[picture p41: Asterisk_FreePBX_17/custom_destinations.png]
  
</a>
<br>
Admin->Custom Destinations->Add Destination  

Target:  
```
pager-callback,${EXTEN},1
```
Description:  
```
Pager Callback
```

Submit and Apply Config  

----------
STEP 3: Add Custom Extension  
----------
<a href="add_extension_1.png">
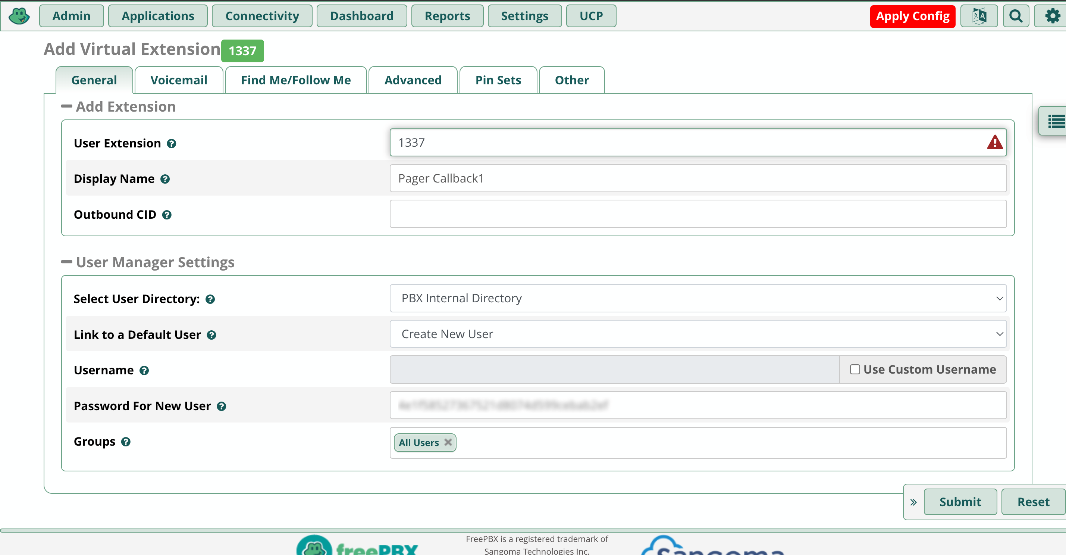
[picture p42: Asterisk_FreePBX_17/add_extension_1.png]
  
</a>
<a href="add_extension_2.png">
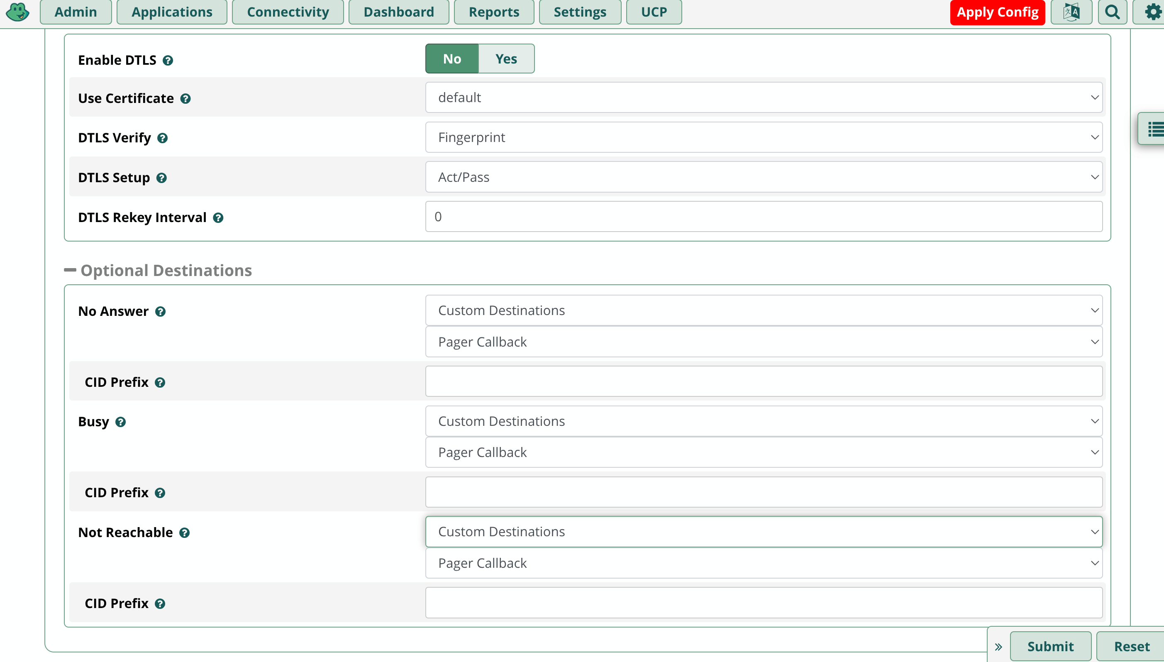
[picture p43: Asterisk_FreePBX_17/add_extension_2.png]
  
</a>
<br>
Connectivity->Extensions->Add Extension->Add Virtual Extension  

General:  

User Extension:  
```
1337
```
Display Name:  
```
Pager Callback 1
```
Advanced:  
For No Answer, Busy, and Not Reachable choose Custom Destination->Pager Callback  

Submit and Apply Config

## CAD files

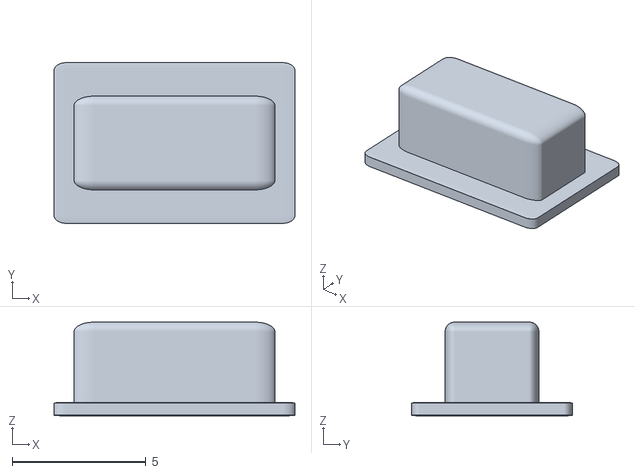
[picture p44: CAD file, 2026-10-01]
3d_prints/Motorola Advisor Classic Power Button v3.stl
9.00 x 6.00 x 3.50

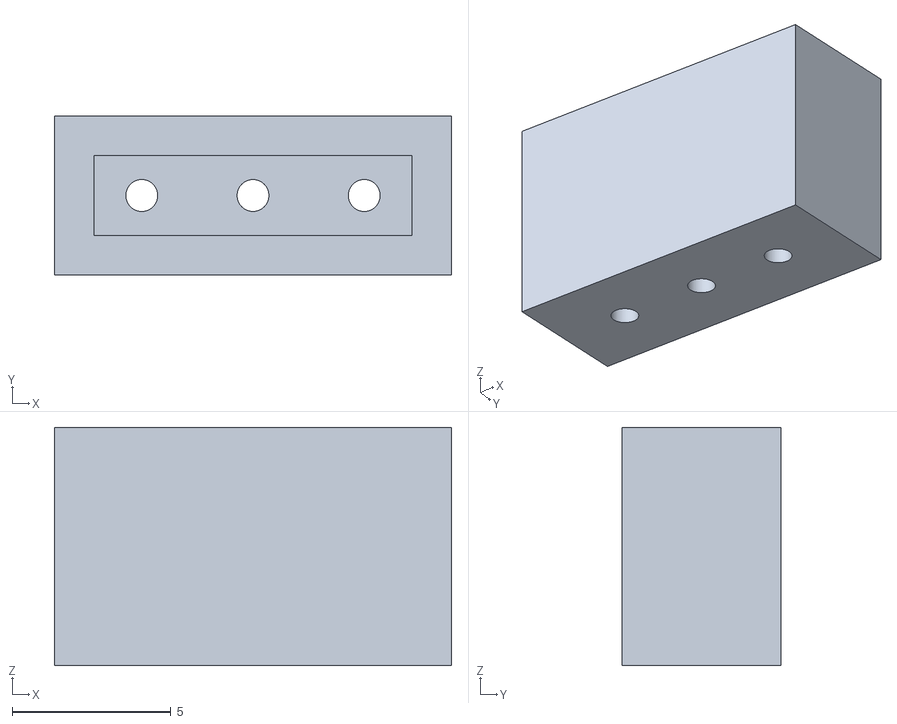
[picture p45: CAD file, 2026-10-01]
3d_prints/Advisor Programmer Breadboard Wire Bundle v2.stl
12.5 x 5.00 x 7.50

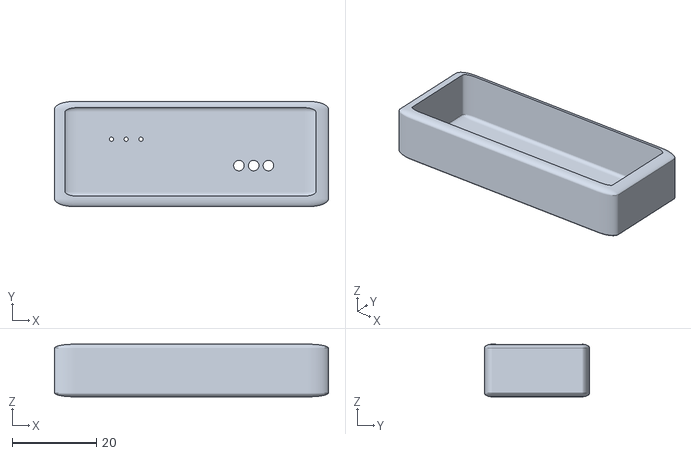
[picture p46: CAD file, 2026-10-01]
3d_prints/Motorola Advisor Classic Programming Cradle v3.stl
65.0 x 25.0 x 12.5

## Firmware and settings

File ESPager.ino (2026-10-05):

// ESPager by Hardcore Corey Harding
// From www.Exploit.Agency
// Tested on original Motorola Advisors (POCSAG and GSC versions)

//Arduino IDE v2.3.10
//esp32:esp32c3-libs@3.3.12
#include <WiFi.h>
#include "esp_wifi.h"
#include <esp_sleep.h>
#include <driver/gpio.h>

//3rd Party Libraries
#include <AsyncTCP.h> // v3.5.0 https://github.com/ESP32Async/AsyncTCP.git
#include <ESPAsyncWebServer.h> // v3.12.1 https://github.com/ESP32Async/ESPAsyncWebServer.git
#include <ElegantOTA.h> // https://github.com/ayushsharma82/ElegantOTA.git

//ESPager Libraries
#include "pocsag_website.h"
#include "gsc_website.h"
#include "settings.h"
#include "pocsag_tx.h"
#include "gsc_tx.h"

#include "pager_ascii_art.h"

AsyncWebServer server(80);

/*--------------------------------------------------------------------
  Utility functions
--------------------------------------------------------------------*/

// WiFiAPmode
void setWiFiAPmode() {
  WiFi.disconnect(true);  // Disconnect from any WiFi
  delay(500);
  WiFi.mode(WIFI_AP);
  WiFi.softAP(APssid, APpassword);
  WiFi.softAPsetHostname(APhostname);
  // Print the AP IP address
  IPAddress APIP = WiFi.softAPIP();
  Serial.print("AP SSID: ");
  Serial.println(APssid);
  Serial.print("AP Password: ");
  Serial.println(APpassword);
  Serial.print("AP Hostname: ");
  Serial.println(APhostname);
  Serial.print("AP IP Address: ");
  Serial.println(APIP);
}

// WiFI STA Mode
void setWiFiSTAmode() {
  WiFi.disconnect(true);  // Disconnect from any WiFi
  delay(500);
  WiFi.setHostname(hostname);
  WiFi.mode(WIFI_MODE_STA);
  WiFi.begin(ssid, password);
  int WiFiRetries = 0;
  while (WiFi.status() != WL_CONNECTED) {
    delay(500);
    Serial.println("Connecting to WiFi...");
    if ((WiFiFallbackCount != 0) && (WiFiRetries == WiFiFallbackCount)) {
      // Unable to connect to network so starting ESP32 as Access Point
      setWiFiAPmode();
      WiFiFallback = true;
      break; //Break the loop
    }
    WiFiRetries++;
  }
  if (!WiFiFallback) {
    Serial.println();
    Serial.println("WiFi connected.");
    Serial.print("IP address: ");
    Serial.println(WiFi.localIP());
  }
}

// Sleep mode
static unsigned long lastISRTime = 0;
void IRAM_ATTR heartbeatISR() {
    unsigned long now = micros();
    if (now - lastISRTime > ISR_CHECK_INTERVAL_US) {  // debounce in uS
        beatCount++;
        lastHeartbeatTime = millis();
        lastISRTime = now;
    }
}

static String htmlEscape(const String &input) {
  String output;
  output.reserve(input.length() + 16);

  for (size_t i = 0; i < input.length(); ++i) {
    char c = input[i];

    switch (c) {
      case '&':
        output += "&amp;";
        break;

      case '<':
        output += "&lt;";
        break;

      case '>':
        output += "&gt;";
        break;

      case '"':
        output += "&quot;";
        break;

      case '\'':
        output += "&#39;";
        break;

      default:
        output += c;
        break;
    }
  }

  return output;
}

/*--------------------------------------------------------------------
  Setup
--------------------------------------------------------------------*/

void setup() {
  setCpuFrequencyMhz(80);

//  Causes compile error for XIAO ESP32 C3 but can save power on other boards
//  pinMode(LED_BUILTIN, OUTPUT);
//  digitalWrite(LED_BUILTIN, LOW);  // Active-low LED

  Serial.begin(115200);
  delay(100);

  // Sleep mode
  // Clear all previous wakeup configurations
  esp_sleep_disable_wakeup_source(ESP_SLEEP_WAKEUP_ALL);
  pinMode(SLEEP_PIN, INPUT_PULLDOWN);
  attachInterrupt(digitalPinToInterrupt(SLEEP_PIN), heartbeatISR, RISING);
  lastHeartbeatTime = millis();
  lastLoopCheck = millis();
  // Enable external GPIO wakeup on SLEEP_PIN
  if (ENABLE_SLEEP) {
  esp_sleep_enable_gpio_wakeup();
  gpio_wakeup_enable((gpio_num_t)SLEEP_PIN, GPIO_INTR_HIGH_LEVEL);
    Serial.println("Setup complete - GPIO wakeup enabled");
  } else {
    Serial.println("Setup complete - sleep mode disabled");
  }
  
  // Reduce WiFi current spikes
  WiFi.setTxPower(WIFI_POWER_DEFINE);

  // Start WiFi Network
  if (APMODE == 1) {
    setWiFiAPmode();
  }
  else {
    setWiFiSTAmode();
  }

  /*
    This file should contain your transmitter setup code, such as:

      pinMode(TX_PIN, OUTPUT);
      digitalWrite(TX_PIN, GSC_IDLE_LEVEL);

    It is included here exactly as in the original sketch.
  */
  #include "tx_setup.h"

  /*--------------------------------------------------------------------
    POCSAG route
  ------------------------------------------------------------------*/

  server.on("/pocsag", HTTP_GET,
    [](AsyncWebServerRequest *request) {

      int params = request->params();

      if (params > 0) {
        if (request->hasParam("msg")) {
          msg = request->getParam("msg")->value();
        }

        if (request->hasParam("cap")) {
          cap = request->getParam("cap")->value();
        }

        if (request->hasParam("baud")) {
          baud = request->getParam("baud")->value();
        }

        if (request->hasParam("function_code")) {
          function_code =
              request->getParam("function_code")->value();
        }

        if (request->hasParam("data_type")) {
          data_type =
              request->getParam("data_type")->value();
        } else {
          data_type = "0";
        }

        if (request->hasParam("inverted")) {
          inverted =
              request->getParam("inverted")->value();
        } else {
          inverted = "0";
        }

        if (request->hasParam("repeat")) {
          repeat =
              request->getParam("repeat")->value();
        }

        String html;

        html.reserve(3000);

// -------------------------------------------------
//  POCSAG Frame Queued – responsive, themed version
// -------------------------------------------------
html = F(
    "<!DOCTYPE html>"
    "<html lang=\"en\">"
    "<head>"
    "<meta charset='UTF-8'>"
    "<meta name='viewport' content='width=device-width, initial-scale=1.0'>"
    "<title>POCSAG Encoder</title>"
    "<style>"
    /* ----- colour variables (same as selection page) ----- */
    ":root{"
    "  --bg-dark:#0a0a12;"
    "  --bg-grad:#0d1a12;"
    "  --bg-deep:#060808;"
    "  --accent:#00ff88;"
    "  --text-main:#33ff66;"
    "  --text-sub:#e0e0e0;"
    "  --panel:#16213e;"
    "  --border:#0f3460;"
    "}"
    "body{"
    "  background-color:var(--bg-dark);"
    "  color:var(--text-main);"
    "  font-family:'Courier New',monospace;"
    "  margin:0;"
    "  padding:2rem;"
    "  text-shadow:"
    "    0 0 2px var(--text-main),"
    "    0 0 8px rgba(51,255,102,.4),"
    "    0 0 20px rgba(51,255,102,.15);"
    "}"
    /* ----- background layers ----- */
    "body::before,body::after,.vignette,.glass{content:\"\";position:fixed;inset:0;pointer-events:none;}"
    "body::before{"
    "  background:radial-gradient(ellipse at 50% 46%,var(--bg-grad) 0%,var(--bg-deep) 78%);"
    "  animation:hum 5.2s steps(6) infinite;"
    "  z-index:-2;"
    "}"
    "@keyframes hum{0%,100%{filter:brightness(0.96);}50%{filter:brightness(1.08);}}"
    "body::after{"
    "  background:repeating-linear-gradient(0deg,"
    "    rgba(0,0,0,.35) 0,"
    "    rgba(0,0,0,.35) 1px,"
    "    transparent 1px,"
    "    transparent 3px);"
    "  animation:scan-drift 2.6s linear infinite;"
    "  z-index:-1;"
    "}"
    "@keyframes scan-drift{to{background-position:0 3px;}}"
    ".vignette{background:radial-gradient(ellipse at 50% 50%,transparent 45%,rgba(0,0,0,.7) 100%);z-index:10;}"
    ".glass{background:radial-gradient(40% 30% at 22% 8%,rgba(255,255,255,.04) 0%,transparent 60%);z-index:11;}"
    "h1{color:var(--accent);margin-top:0;}"
    /* ----- stacked details form ----- */
    "form.details{"
    "  display:flex;"
    "  flex-direction:column;"
    "  gap:0.6rem;"
    "  max-width:40rem;"
    "  margin:1rem 0;"
    "}"
    "form.details label{"
    "  font-weight:bold;"
    "  color:#aaa;"
    "}"
    "form.details span{"
    "  color:var(--text-sub);"
    "  padding:0.4rem 0.6rem;"
    "  background:var(--panel);"
    "  border:1px solid var(--border);"
    "  border-radius:4px;"
    "  word-break:break-word;"
    "}"
    "form.action{margin-top:1rem;}"
    "input[type='submit']{"
    "  background:var(--border);"
    "  color:var(--accent);"
    "  border:1px solid var(--accent);"
    "  border-radius:4px;"
    "  padding:0.6rem 1.2rem;"
    "  font-family:monospace;"
    "  cursor:pointer;"
    "}"
    "input[type='submit']:hover{"
    "  background:var(--accent);"
    "  color:#1a1a2e;"
    "}"
    "@media (max-width:600px){"
    "  body{padding:1rem;}"
    "  h1{font-size:1.5rem;}"
    "}"
    "</style>"
    "</head>"
    "<body>"
    "<div class=\"vignette\"></div>"
    "<div class=\"glass\"></div>"
    "<h1>POCSAG Frame Queued</h1>"
    "<form class='details'>"
    "<label>MESSAGE:</label><span>"
);

html += htmlEscape(msg);

html += F(
    "</span>"
    "<label>CAPCODE:</label><span>"
);
html += htmlEscape(cap);

html += F(
    "</span>"
    "<label>BAUD RATE:</label><span>"
);
html += htmlEscape(baud);

html += F(
    "</span>"
    "<label>FUNCTION CODE:</label><span>"
);
html += htmlEscape(function_code);

html += F(
    "</span>"
    "<label>DATA TYPE:</label><span>"
);
html += htmlEscape(data_type);

html += F(
    "</span>"
    "<label>INVERTED:</label><span>"
);
html += htmlEscape(inverted);

html += F(
    "</span>"
    "<label>TIMES TO REPEAT:</label><span>"
);
html += htmlEscape(repeat);

html += F(
    "</span>"
    "</form>"
    "<form class='action' action='/pocsag' method='GET'>"
    "<input type='submit' value='Send Another POCSAG Page'>"
    "</form>"
    "<form class='action' action='/' method='GET'>"
    "<input type='submit' value='Return to Encoder Selection'>"
    "</form>"
    "</body>"
    "</html>"
);

        request->send(200, "text/html", html);

        WebsiteDelivered = true;
        TransmitPocsag = true;

        Serial.println("---------------");
        Serial.println("POCSAG FRAME");
        Serial.print("MESSAGE: ");
        Serial.println(msg);
        Serial.print("CAPCODE: ");
        Serial.println(cap);
        Serial.print("BAUD RATE: ");
        Serial.println(baud);
        Serial.print("FUNCTION CODE: ");
        Serial.println(function_code);
        Serial.print("DATA TYPE: ");
        Serial.println(data_type);
        Serial.print("INVERTED: ");
        Serial.println(inverted);
        Serial.print("TIMES TO REPEAT: ");
        Serial.println(repeat);
        Serial.println("---------------");
      }

      else {
        String html = String(pocsag_index_html);

        html.replace("{{MSG}}", msg);
        html.replace("{{CAP}}", cap);

        html.replace(
            "{{BAUD_512}}",
            baud == "512" ? "selected" : ""
        );

        html.replace(
            "{{BAUD_1200}}",
            baud == "1200" ? "selected" : ""
        );

        html.replace(
            "{{BAUD_2400}}",
            baud == "2400" ? "selected" : ""
        );

        html.replace(
            "{{FC_0}}",
            function_code == "0" ? "selected" : ""
        );

        html.replace(
            "{{FC_1}}",
            function_code == "1" ? "selected" : ""
        );

        html.replace(
            "{{FC_2}}",
            function_code == "2" ? "selected" : ""
        );

        html.replace(
            "{{FC_3}}",
            function_code == "3" ? "selected" : ""
        );

        html.replace(
            "{{data_type_0}}",
            data_type == "0" ? "selected" : ""
        );

        html.replace(
            "{{data_type_1}}",
            data_type == "1" ? "selected" : ""
        );

        html.replace(
            "{{data_type_2}}",
            data_type == "2" ? "selected" : ""
        );

        html.replace(
            "{{INVERTED}}",
            inverted == "1" ? "checked" : ""
        );

        html.replace("{{REPEAT}}", repeat);

        request->send(200, "text/html", html);
      }
    }
  );

  /*--------------------------------------------------------------------
    GSC route
  ------------------------------------------------------------------*/

  server.on("/gsc", HTTP_GET,
    [](AsyncWebServerRequest *request) {

      int params = request->params();

      if (params > 0) {
        if (request->hasParam("msg")) {
          gscMsg = request->getParam("msg")->value();
        }

        if (request->hasParam("cap")) {
          gscCap = request->getParam("cap")->value();
        }

        if (request->hasParam("function_code")) {
          gscFunctionCode =
              request->getParam("function_code")->value();
        }

        if (request->hasParam("data_type")) {
          gscDataType =
              request->getParam("data_type")->value();
        } else {
          gscDataType = "0";
        }

        String gscData_type =
            (gscDataType == "0") ? "Numeric" : "Alphanumeric";

        String html;

        html.reserve(3000);

// -------------------------------------------------
//  GSC Frame Queued – responsive, themed version
// -------------------------------------------------
html = F(
    "<!DOCTYPE html>"
    "<html lang=\"en\">"
    "<head>"
    "<meta charset='UTF-8'>"
    "<meta name='viewport' content='width=device-width, initial-scale=1.0'>"
    "<title>GSC Encoder</title>"
    "<style>"
    /* ----- colour variables (same as selection page) ----- */
    ":root{"
    "  --bg-dark:#0a0a12;"
    "  --bg-grad:#0d1a12;"
    "  --bg-deep:#060808;"
    "  --accent:#00ff88;"
    "  --text-main:#33ff66;"
    "  --text-sub:#e0e0e0;"
    "  --panel:#16213e;"
    "  --border:#0f3460;"
    "}"
    "body{"
    "  background-color:var(--bg-dark);"
    "  color:var(--text-main);"
    "  font-family:'Courier New',monospace;"
    "  margin:0;"
    "  padding:2rem;"
    "  text-shadow:"
    "    0 0 2px var(--text-main),"
    "    0 0 8px rgba(51,255,102,.4),"
    "    0 0 20px rgba(51,255,102,.15);"
    "}"
    /* ----- background layers (hum, scan‑lines, vignette, glass) ----- */
    "body::before,body::after,.vignette,.glass{content:\"\";position:fixed;inset:0;pointer-events:none;}"
    "body::before{"
    "  background:radial-gradient(ellipse at 50% 46%,var(--bg-grad) 0%,var(--bg-deep) 78%);"
    "  animation:hum 5.2s steps(6) infinite;"
    "  z-index:-2;"
    "}"
    "@keyframes hum{0%,100%{filter:brightness(0.96);}50%{filter:brightness(1.08);}}"
    "body::after{"
    "  background:repeating-linear-gradient(0deg,"
    "    rgba(0,0,0,.35) 0,"
    "    rgba(0,0,0,.35) 1px,"
    "    transparent 1px,"
    "    transparent 3px);"
    "  animation:scan-drift 2.6s linear infinite;"
    "  z-index:-1;"
    "}"
    "@keyframes scan-drift{to{background-position:0 3px;}}"
    ".vignette{background:radial-gradient(ellipse at 50% 50%,transparent 45%,rgba(0,0,0,.7) 100%);z-index:10;}"
    ".glass{background:radial-gradient(40% 30% at 22% 8%,rgba(255,255,255,.04) 0%,transparent 60%);z-index:11;}"
    "h1{color:var(--accent);margin-top:0;}"
    /* ----- stacked details form ----- */
    "form.details{"
    "  display:flex;"
    "  flex-direction:column;"
    "  gap:0.6rem;"
    "  max-width:40rem;"
    "  margin:1rem 0;"
    "}"
    "form.details label{"
    "  font-weight:bold;"
    "  color:#aaa;"
    "}"
    "form.details span{"
    "  color:var(--text-sub);"
    "  padding:0.4rem 0.6rem;"
    "  white-space:pre-wrap;"
    "  word-break:break-word;"
    "  background:var(--panel);"
    "  border:1px solid var(--border);"
    "  border-radius:4px;"
    "}"
    "form.action{margin-top:1rem;}"
    "input[type='submit']{"
    "  background:var(--border);"
    "  color:var(--accent);"
    "  border:1px solid var(--accent);"
    "  border-radius:4px;"
    "  padding:0.6rem 1.2rem;"
    "  font-family:monospace;"
    "  cursor:pointer;"
    "}"
    "input[type='submit']:hover{"
    "  background:var(--accent);"
    "  color:#1a1a2e;"
    "}"
    "@media (max-width:600px){"
    "  body{padding:1rem;}"
    "  h1{font-size:1.5rem;}"
    "}"
    "</style>"
    "</head>"
    "<body>"
    "<div class=\"vignette\"></div>"
    "<div class=\"glass\"></div>"
    "<h1>GSC Frame Queued</h1>"
    "<form class='details'>"
    "<label>MESSAGE:</label><span>"
);

html += htmlEscape(gscMsg);

html += F(
    "</span>"
    "<label>CAPCODE:</label><span>"
);

html += htmlEscape(gscCap);

html += F(
    "</span>"
    "<label>BAUD RATE:</label><span>600 bps</span>"
    "<label>FUNCTION CODE:</label><span>"
);

html += htmlEscape(gscFunctionCode);

html += F(
    "</span>"
    "<label>DATA TYPE:</label><span>"
);

html += gscData_type;   // already escaped when you set it

html += F(
    "</span>"
    "</form>"
    "<form class='action' action='/gsc' method='GET'>"
    "<input type='submit' value='Send Another GSC Page'>"
    "</form>"
    "<form class='action' action='/' method='GET'>"
    "<input type='submit' value='Return to Encoder Selection'>"
    "</form>"
    "</body>"
    "</html>"
);

        request->send(200, "text/html", html);

        Serial.println("---------------");
        Serial.println("GSC FRAME");
        Serial.print("MESSAGE: ");
        Serial.println(gscMsg);
        Serial.print("CAPCODE: ");
        Serial.println(gscCap);
        Serial.println("BAUD RATE: 600");
        Serial.print("FUNCTION CODE: ");
        Serial.println(gscFunctionCode);
        Serial.print("DATA TYPE: ");
        Serial.println(gscData_type);
        Serial.println("---------------");

        gscWebsiteDelivered = true;
        transmitGSC = true;

        Serial.println("---------------");
        Serial.println("GSC FRAME");
        Serial.print("MESSAGE: ");
        Serial.println(gscMsg);
        Serial.print("CAPCODE: ");
        Serial.println(gscCap);
        Serial.print("FUNCTION CODE: ");
        Serial.println(gscFunctionCode);
        Serial.print("DATA TYPE: ");
        Serial.println(gscData_type);
        Serial.println("---------------");
      }

      else {
        String html = String(gsc_index_html);

        html.replace("{{MSG}}", gscMsg);
        html.replace("{{CAP}}", gscCap);

        html.replace(
            "{{FC_0}}",
            gscFunctionCode == "0" ? "selected" : ""
        );

        html.replace(
            "{{FC_1}}",
            gscFunctionCode == "1" ? "selected" : ""
        );

        html.replace(
            "{{FC_2}}",
            gscFunctionCode == "2" ? "selected" : ""
        );

        html.replace(
            "{{FC_3}}",
            gscFunctionCode == "3" ? "selected" : ""
        );

        html.replace(
            "{{DATA_TYPE_ALPHA}}",
            gscDataType == "1" ? "selected" : ""
        );

        html.replace(
            "{{DATA_TYPE_NUMERIC}}",
            gscDataType == "0" ? "selected" : ""
        );

        request->send(200, "text/html", html);
      }
    }
  );

  /*--------------------------------------------------------------------
    Root website
  ------------------------------------------------------------------*/
  server.on("/", HTTP_GET, [](AsyncWebServerRequest *request) {
String html = R"rawliteral(
<!DOCTYPE html>
<html lang="en">
<head>
<meta charset="utf-8">
<!-- make the viewport follow the device width -->
<meta name="viewport" content="width=device-width, initial-scale=1">

<style>
/* ---------- colours & utilities ---------- */
:root{
  --bg-dark:#0a0a12;
  --bg-grad:#0d1a12;
  --bg-deep:#060808;
  --accent:#00ff88;
  --text-main:#33ff66;
  --text-sub:#e0e0e0;
  --border:#0f3460;
}
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
void loop() {
  // Sleep mode
  unsigned long now = millis();
  // Non-blocking timer check
  if (ENABLE_SLEEP && (now - lastLoopCheck >= LOOP_CHECK_INTERVAL)) {
    lastLoopCheck = now;
    unsigned long timeSinceLastBeat = now - lastHeartbeatTime;
    // Enter sleep only if timeout exceeded and sleep is enabled
    if (ENABLE_SLEEP && timeSinceLastBeat > SLEEP_TIMEOUT) {
      Serial.println("ESP32 entering light sleep (GPIO wakeup only)...");
      Serial.flush();
      disableCore0WDT();  // Disable before sleeping
      esp_light_sleep_start();
      Serial.println("ESP32 woke from light sleep");
      Serial.flush();
    }
  }

  ElegantOTA.loop();

  /*--------------------------------------------------------------
    POCSAG transmission
  --------------------------------------------------------------*/

  if (WebsiteDelivered) {
    WebsiteDelivered = false;

    if (TransmitPocsag) {
      TransmitPocsag = false;

      bool success = txPOCSAGMessage(
          static_cast<long>(cap.toInt()),
          msg.c_str(),
          baud.toInt(),
          function_code.toInt(),
          data_type.toInt(),
          inverted.toInt(),
          repeat.toInt()
      );

      if (success) {
        Serial.println("POCSAG transmission complete.");
      } else {
        Serial.println("POCSAG transmission failed.");
      }
    }
  }

  /*--------------------------------------------------------------
    GSC transmission
  --------------------------------------------------------------*/

  if (gscWebsiteDelivered) {
    gscWebsiteDelivered = false;

    if (transmitGSC) {
      transmitGSC = false;

      uint32_t capcode =
          static_cast<uint32_t>(gscCap.toInt());

      uint8_t functionCode =
          static_cast<uint8_t>(gscFunctionCode.toInt());

      GSCMessageType messageType =
          gscDataType == "0"
              ? GSC_MESSAGE_NUMERIC
              : GSC_MESSAGE_ALPHA;

      bool success = sendGSCFrame(
          capcode,
          gscMsg.c_str(),
          messageType,
          functionCode
      );

      if (success) {
        Serial.println("GSC transmission complete.");
      } else {
        Serial.println("GSC transmission failed.");
      }
    }
  }
}

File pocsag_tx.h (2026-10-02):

// ESPager by Hardcore Corey Harding
/*-------------------------------------------------------------
   POCSAG encoder for ESP32
   // Based on rpitx by F5OEO (https://github.com/F5OEO/rpitx)
   // rpitx License: "./3RD_PARTY_LICENSE/license_rpitx.h" (https://github.com/F5OEO/rpitx/blob/master/LICENCE)
   // Also adapted from Arduino Nano reference code from:
   //   https://hackaday.io/project/183267-motolora-advisor
   // advisorradio.ino License: "./3RD_PARTY_LICENSE/license_advisorradio.h"
-------------------------------------------------------------*/

#include <Arduino.h>
#include <stdint.h>
#include <string.h>
#include <driver/gpio.h>

/*-------------------------------------------------------------------
   Protocol‑level constants
--------------------------------------------------------------------*/
#define SYNC               0x7CD215D8UL
#define IDLE               0x7A89C197UL
#define FRAME_SIZE         2
#define BATCH_SIZE         16
#define PREAMBLE_LENGTH    576
#define FLAG_ADDRESS       0x000000UL
#define FLAG_MESSAGE       0x100000UL
#define TEXT_BITS_PER_WORD 20
#define TEXT_BITS_PER_CHAR 7
#define CRC_BITS           10
#define NUMERIC_BITS_PER_WORD   20
#define NUMERIC_BITS_PER_DIGIT   4
#define NUMERIC_DIGITS_PER_WORD (NUMERIC_BITS_PER_WORD / NUMERIC_BITS_PER_DIGIT)

/*-------------------------------------------------------------------
   BCH‑CRC helpers – generate the 10‑bit CRC and overall parity
--------------------------------------------------------------------*/
static uint32_t crc(uint32_t msg) {
    const uint32_t poly = 0b11101101001U << 20;
    uint32_t reg = msg << CRC_BITS;
    for (int i = 0; i <= 20; ++i) {
        if ((reg >> (30 - i)) & 1U)
            reg ^= (poly >> i);
    }
    return reg & 0x3FFU;
}

static uint32_t parity(uint32_t x) {
    uint32_t p = 0;
    for (int i = 0; i < 32; ++i) {
        p ^= (x & 1U);
        x >>= 1;
    }
    return p;
}

static uint32_t encodeCodeword(uint32_t data) {
    uint32_t cw = (data << CRC_BITS) | crc(data);
    return (cw << 1) | parity(cw);
}

/*-------------------------------------------------------------------
   ASCII message encoding – packs 7‑bit characters into 20‑bit words
--------------------------------------------------------------------*/
static uint32_t encodeASCII(uint32_t offset,
                            const char *txt,
                            uint32_t *out) {
    uint32_t words = 0;
    uint32_t cur   = 0;
    uint32_t bits  = 0;
    uint32_t pos   = offset;

    while (*txt) {
        unsigned char c = static_cast<unsigned char>(*txt++);
        for (int i = 0; i < TEXT_BITS_PER_CHAR; ++i) {
            cur <<= 1;
            cur |= (c >> i) & 1U;
            bits++;
            if (bits == TEXT_BITS_PER_WORD) {
                *out++ = encodeCodeword(cur | FLAG_MESSAGE);
                ++words;
                cur  = 0;
                bits = 0;
                ++pos;
                if (pos == BATCH_SIZE) {
                    *out++ = SYNC;
                    ++words;
                    pos = 0;
                }
            }
        }
    }

    if (bits) {
        cur <<= TEXT_BITS_PER_WORD - bits;
        *out++ = encodeCodeword(cur | FLAG_MESSAGE);
        ++words;
        ++pos;
        if (pos == BATCH_SIZE) {
            *out++ = SYNC;
            ++words;
        }
    }
    return words;
}

/*-------------------------------------------------------------------
   Numeric helpers – translate characters to 4‑bit POCSAG digits
--------------------------------------------------------------------*/
static uint32_t digitValue(char c) {
    if (c >= '0' && c <= '9')
        return c - '0';
    switch (c) {
        case 'S': case 's': return 0xA;
        case 'U': case 'u': return 0xB;
        case ' ':          return 0xC;
        case '-':          return 0xD;
        case ']': case ')':return 0xE;
        case '[': case '(':return 0xF;
        default:           return 0xC;
    }
}

static uint32_t encodeNumeric(uint32_t offset,
                              const char *txt,
                              uint32_t *out) {
    uint32_t words = 0;
    uint32_t cur   = 0;
    uint32_t bits  = 0;
    uint32_t pos   = offset;

    while (*txt) {
        uint32_t digit = digitValue(*txt++);
        for (uint32_t bit = 0; bit < NUMERIC_BITS_PER_DIGIT; ++bit) {
            cur <<= 1;
            cur |= (digit >> bit) & 1U;
            bits++;
            if (bits == NUMERIC_BITS_PER_WORD) {
                *out++ = encodeCodeword(cur | FLAG_MESSAGE);
                ++words;
                cur  = 0;
                bits = 0;
                ++pos;
                if (pos == BATCH_SIZE) {
                    *out++ = SYNC;
                    ++words;
                    pos = 0;
                }
            }
        }
    }

    if (bits) {
        while (bits < NUMERIC_BITS_PER_WORD) {
            uint32_t paddingDigit = 0xC;
            for (uint32_t bit = 0;
                 bit < NUMERIC_BITS_PER_DIGIT && bits < NUMERIC_BITS_PER_WORD;
                 ++bit) {
                cur <<= 1;
                cur |= (paddingDigit >> bit) & 1U;
                ++bits;
            }
        }
        *out++ = encodeCodeword(cur | FLAG_MESSAGE);
        ++words;
        ++pos;
        if (pos == BATCH_SIZE) {
            *out++ = SYNC;
            ++words;
        }
    }
    return words;
}

/*-------------------------------------------------------------------
   Address handling – determines the word offset inside a batch
--------------------------------------------------------------------*/
static inline int addressOffset(long addr) {
    return (addr & 0x7) * FRAME_SIZE;
}

/*-------------------------------------------------------------------
   Batch helpers
--------------------------------------------------------------------*/
static size_t messageSyncCount(size_t offset,
                               size_t messageWords) {
    size_t syncs = 0;
    size_t pos   = offset;
    for (size_t i = 0; i < messageWords; ++i) {
        ++pos;
        if (pos == BATCH_SIZE) {
            ++syncs;
            pos = 0;
        }
    }
    return syncs;
}

static size_t batchPadding(size_t words) {
    return (BATCH_SIZE + 1 - (words % (BATCH_SIZE + 1))) %
           (BATCH_SIZE + 1);
}
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

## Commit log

2026-10-01 Initial Commit - Add Files
    [Advisor Programmer Breadboard Wire Bundle v2.stl, Motorola Advisor Classic Power Button v3.stl, Motorola Advisor Classic Programming Cradle v3.stl]
2026-10-02 Formatting, Readme, Minor Bug Fix
    [ESPager.ino, gsc_tx.h, pocsag_tx.h]
2026-10-05 Update code to compile on XIAO ESP32 C3
2026-10-05 Update README for XIAO ESP32C3
2026-10-05 Add XIAO Wiring Diagram
